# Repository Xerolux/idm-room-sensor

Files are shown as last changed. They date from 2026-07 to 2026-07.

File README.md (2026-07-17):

<div align="center">

# IDM Smart Climate Platform

**Open-source climate bridge, room sensing and condensation protection for IDM heat pumps**







</div>

> [!CAUTION]
> **Experimental developer edition. Not production-ready and not validated on a real IDM installation.**  
> Do not connect unverified hardware to a heat pump. Independent condensation protection remains mandatory for cooling tests.

<!-- SAFETY:NOT_PRODUCTION --><!-- SAFETY:WORK_IN_PROGRESS -->

## What this project contains

The platform combines three hardware approaches and a software-first GLT bridge:

| Component | Purpose | Status |
|---|---|---|
| ESP Room Sensor | Local SHT45 sensing, ESPHome, 0–10 V humidity and real KTY81-210 | Design prototype |
| Classic Sensor | Compact local sensor without Wi-Fi | Design prototype |
| Fake Sensor / Bridge | Receives HA/KNX/MQTT values and emulates the original IDM interface | Design prototype |
| Climate Engine | Selects the most critical room by dew-point margin | Functional HA example |
| `set_external_climate` | Native service present on `idm-heatpump-hass` main; stable-package fallback included here | Software tested, real device untested |
| Pipe Dew-Point Guard | Independent pipe-temperature/condensation safety concept | Documentation only |

## Confirmed original sensor information

The available LCN-FTW04 documentation identifies a combined room humidity/temperature sensor, a 0–10 V humidity output, KTY temperature element and 14–30 V DC supply. Only one room humidity sensor is intended for the Navigator; individual room temperatures may come from room units.

Current project terminal mapping must be verified against the exact IDM wiring diagram before connection:

| Function | Project signal |
|---|---|
| Supply | 14–30 V DC |
| Humidity | 0–10 V, working assumption 0–100 % RH |
| Temperature | KTY81-210 equivalent |
| Ground | Common reference |

## Preferred architecture

```text
KNX / ESPHome / Zigbee / MQTT room sensors
                    │
                    ▼
        Home Assistant Climate Engine
        - dew point per room
        - minimum dew-point margin
        - stale sensor detection
        - configurable fallback
                    │
          ┌─────────┴─────────┐
          ▼                   ▼
 GLT / Modbus registers   Analog fallback bridge
 1650…1663 temperature    0–10 V humidity
 1692 humidity            KTY emulation
          │                   │
          └─────────┬─────────┘
                    ▼
               IDM Navigator

Independent pipe dew-point switch / cooling inhibit
```

## Project checklist

### Documentation and repository
- [x] Professional README
- [x] GitHub Pages / Docsify structure
- [x] Wiki source pages
- [x] Issue and pull-request templates
- [x] Security, contributing and code-of-conduct files
- [x] Community test forms
- [x] Architecture and safety documentation

### Home Assistant and IDM integration
- [x] Multi-room climate-engine package selecting the highest dew point
- [x] Example automation for GLT register writes
- [x] Stale-input detection using Home Assistant `last_reported`
- [x] `set_external_climate` reference aligned with current upstream interfaces
- [x] Local service-contract and dew-point tests
- [x] Current register mapping reviewed against `idm-heatpump-api` main
- [ ] Release `set_external_climate` in a tagged `idm-heatpump-hass` version
- [ ] Real-device Modbus verification
- [ ] Confirm that the selected IDM configuration uses GLT values for cooling control

### ESPHome and firmware
- [x] ESPHome bridge configuration
- [x] Home Assistant-controlled temperature/humidity inputs
- [x] Stale-data timeout and conservative fallback concept
- [x] Dew-point calculation example
- [x] MCP4725 output component source
- [x] KTY lookup and calibration framework
- [x] Compile against the selected ESPHome release
- [x] Local authenticated web UI with confirmation-gated calibration/reset
- [x] Native ESP-IDF target with I/O, fail-safe runtime, NVS, API and OTA
- [ ] Hardware-in-the-loop test
- [ ] OTA recovery test

### Hardware
- [x] Block-level schematics and KiCad project structure
- [x] Board outlines and component placement concepts
- [x] Preliminary BOM and JLCPCB templates
- [x] Enclosure STL/OpenSCAD prototypes
- [ ] Replace every prototype symbol/footprint with verified manufacturer footprint
- [ ] Complete ERC/DRC with KiCad 9
- [ ] Review switch-mode power-supply layout against regulator datasheet
- [ ] Route and validate analog ground/current return paths
- [ ] Manufacture prototype
- [ ] Validate 0–10 V linearity and load drive
- [ ] Validate KTY emulation excitation voltage/current
- [ ] EMC, ESD, thermal and long-term tests

### Real installation
- [ ] Measure the original sensor at multiple humidity points
- [ ] Measure IDM KTY input using a resistance decade
- [ ] Confirm safe open-circuit and short-circuit behavior
- [ ] Heating-only observation
- [ ] Cooling test with independent dew-point switch
- [ ] Multi-week logging and fault injection

## Quick start for contributors

1. Read [Safety](pages/#/cooling-safety) and [Validation Plan](pages/#/validation).
2. Choose the next unblocked item from the [prioritized task list](TASKS.md).
3. Do not mark measurements as verified without raw data and test conditions.
4. Open an issue using the measurement or hardware-test template.

## Repository layout

```text
hardware/                 KiCad prototypes, BOM, CPL templates, enclosures
firmware/                 ESPHome and custom component sources
homeassistant/            Climate engine, automations and dashboard examples
idm-heatpump-hass/        Upstream service patch and tests
pages/                    GitHub Pages / Docsify site
wiki/                     GitHub Wiki source pages
docs/                     Technical documentation and validation plans
manufacturing/            Shared fabrication notes and release checklist
.github/                  Workflows, issue templates and contribution automation
```

ESPHome and native ESP-IDF builds use the pinned toolchains documented in
[firmware/BUILDING.md](firmware/BUILDING.md).

## Safety

This project is unaffiliated with IDM Energiesysteme. It is experimental open hardware. Incorrect humidity or temperature values can defeat condensation protection and cause water damage. Use an independent, hard-wired pipe dew-point switch during development and commissioning.

## Community Work Packages

- `work-packages/WP01-hardware`
- `work-packages/WP02-firmware`
- `work-packages/WP03-home-assistant`
- `work-packages/WP04-documentation`
- `work-packages/WP05-validation`

See the [prioritized task list](TASKS.md) and the compact
[project-status summary](PROJECT_STATUS.md).

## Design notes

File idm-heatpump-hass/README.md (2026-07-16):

# Proposed upstream changes

The current `idm-heatpump-hass` main branch contains
`idm_heatpump.set_external_climate` (commit `bd41999`, 2026-07-16). This
directory now preserves a dependency-light contract reference and standalone
tests for review from the climate-platform side.

The service has not yet shipped in a tagged release and has not been validated
against a real heat pump. The Home Assistant package therefore uses
`write_register` for v0.8.2 compatibility.

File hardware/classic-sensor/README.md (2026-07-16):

# IDM-RoomSensor-Classic Rev. A

Enthalten: KiCad-Schaltplan, PCB-Layout/Platzierung, BOM, Firmware-Grundlage und Gehäuse als STL/OpenSCAD.

**Versorgung:** Die Classic-Platine wird aus den 24 V der IDM versorgt und besitzt kein WLAN/ESP.

IDM-Klemmen: 43=KTY-Temperatursignal, 42=+14–32 V DC, 41=gemeinsamer GND/KTY-Rückleiter, 40=Feuchte 0–10 V.

Annahme: 0 V = 0 % rF, 10 V = 100 % rF.

## Status
Rev.-A-Entwicklungsgrundlage, **nicht produktionsfreigegeben**. Vor Bestellung und Anschluss: Footprints, ERC/DRC, Analogskalierung, Schutzbeschaltung, EMV und reale IDM-Kennlinie prüfen und kalibrieren.

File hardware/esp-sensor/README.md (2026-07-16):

# IDM-RoomSensor-ESP Rev. A

Enthalten: KiCad-Schaltplan, PCB-Layout/Platzierung, BOM, Firmware-Grundlage und Gehäuse als STL/OpenSCAD.

**Versorgung:** Der ESP wird über die 24 V der IDM versorgt; 24 V werden auf 5 V und 3,3 V gewandelt.

IDM-Klemmen: 43=KTY-Temperatursignal, 42=+14–32 V DC, 41=gemeinsamer GND/KTY-Rückleiter, 40=Feuchte 0–10 V.

Annahme: 0 V = 0 % rF, 10 V = 100 % rF.

## Status
Rev.-A-Entwicklungsgrundlage, **nicht produktionsfreigegeben**. Vor Bestellung und Anschluss: Footprints, ERC/DRC, Analogskalierung, Schutzbeschaltung, EMV und reale IDM-Kennlinie prüfen und kalibrieren.

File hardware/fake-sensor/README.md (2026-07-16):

# IDM Fake Sensor ESP – Revision A

Diese Platine empfängt Temperatur- und Feuchtewerte aus Home Assistant und simuliert gegenüber der IDM AERO ALM den originalen Temperatur-/Feuchtesensor.

## Ausgänge

| IDM-Klemme | Signal |
|---|---|
| 43 | emuliertes KTY-Temperatursignal |
| 42 | +14–32 V DC Versorgung |
| 41 | gemeinsamer GND/KTY-Rückleiter |
| 40 | simulierte Feuchte 0–10 V |

Der ESP32 wird vollständig aus den 24 V der IDM versorgt.

## Home Assistant

Home Assistant setzt zwei ESPHome-Number-Entitäten:

- simulierte relative Feuchte
- simulierte Raumtemperatur

Damit können Mittelwerte, Maximalwerte oder der ungünstigste Raum an die Wärmepumpe weitergegeben werden. Für die Kühlung sollte eher der **kritischste Raum** verwendet werden als ein Durchschnitt.

## Fail-safe

Bei fehlenden Aktualisierungen werden standardmäßig ausgegeben:

- 80 % rF
- 28 °C

Die Werte sind absichtlich konservativ. Zusätzlich sollte die vorhandene Taupunktüberwachung der Anlage aktiv bleiben.

## Wichtige technische Einschränkung

Die Feuchtesimulation ist klar: DAC plus Operationsverstärker erzeugen 0–10 V.

Die Temperatursimulation muss noch elektrisch validiert werden. Der Entwurf verwendet einen Digitalpotentiometer plus Festwiderstandsnetzwerk zur Nachbildung eines KTY81-210. Vor Anschluss müssen an der IDM gemessen werden:

1. Leerlaufspannung an 43 gegen 41,
2. Messstrom durch einen echten KTY81-210,
3. zulässige Spannung an den Anschlüssen des Digitalpotentiometers,
4. tatsächliche Widerstandskennlinie, die die IDM erwartet.

Falls Spannung oder Strom für einen Digitalpotentiometer ungeeignet sind, muss die Temperaturstufe durch eine galvanisch isolierte Widerstandsmatrix oder PhotoMOS-Lösung ersetzt werden.

## Status des Layouts

Das KiCad-PCB enthält Boardkontur und Bauteilplatzierung. Es ist eine Rev.-A-Entwicklungsgrundlage und **nicht produktionsfreigegeben**. Vor Bestellung:

- Footprints kontrollieren,
- Schaltplan in modernes KiCad-Format übernehmen,
- vollständig routen,
- ERC/DRC ausführen,
- 0–10-V-Verstärkung dimensionieren,
- Temperaturstufe vermessen und kalibrieren,
- EMV- und Schutzbeschaltung prüfen.

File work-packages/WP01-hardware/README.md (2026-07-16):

# Hardware engineering

- [ ] Power and protection review
- [ ] 0–10 V stage
- [ ] KTY emulation
- [ ] PCB routing
- [ ] Fabrication outputs
- [ ] Enclosures
- [ ] Test points

Results must include conditions, equipment and raw data.

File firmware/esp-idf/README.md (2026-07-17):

# Native ESP-IDF firmware

This target implements the fake-sensor bridge directly on ESP-IDF. It shares
the host-tested dew-point, quality, bridge-state, calibration and analog-output
cores with the ESPHome variant.

> [!CAUTION]
> This remains experimental firmware for unverified prototype hardware. It
> does not replace an independent, hard-wired condensation guard.

## Implemented behavior

- boots into configured fail-safe humidity and temperature values before
  networking starts;
- drives an MCP4725 humidity DAC and AD5242 temperature digipot over I2C;
- validates humidity, temperature, source length and command quality;
- returns to fail-safe output after the command stale timeout;
- latches output failures, retries the I2C path and reports recovery;
- stores CRC-protected calibration V2 records in NVS, verifies writes and
  migrates valid V1 records;
- connects as a Wi-Fi station when an SSID is configured and otherwise remains
  local-only;
- exposes versioned diagnostics and authenticated mutation endpoints;
- uses the ESP task watchdog, brownout detection and OTA rollback support;
- accepts only HTTPS OTA URLs using the ESP certificate bundle;
- confirms a new OTA image only after a health window, never blindly at boot;
- redacts sensor data on the diagnostics endpoint when no API token is set.

## Build

PlatformIO 6.1.19 and the pinned pioarduino ESP32 platform are used for the
reproducible build:

```bash
python3 -m pip install platformio==6.1.19
make build-esp-idf
```

The equivalent direct command is:

```bash
platformio run --project-dir firmware/esp-idf
```

The generated `sdkconfig.idm-native` and `.pio/` directory are local build
artifacts and are ignored.

## Configuration

Run PlatformIO's ESP-IDF menu configuration and open **IDM native firmware**:

```bash
platformio run --project-dir firmware/esp-idf --target menuconfig
```

At minimum, review:

- Wi-Fi SSID/password and hostname;
- a random HTTP bearer token of at least 16 characters;
- I2C pins and device addresses;
- fail-safe values, stale timeout and minimum command quality;
- factory analog calibration.

An empty Wi-Fi SSID keeps the target local-only. An empty API token disables
every mutating endpoint. The diagnostic endpoint remains readable without a
token, but when no token is configured it **redacts** sensor values
(effective humidity/temperature, dew point, command source, output codes) and
publishes only operational fields (bridge state, safe/stale/fault flags,
uptime, heap). Configure `IDM_API_TOKEN` to receive full diagnostics behind
the same bearer gate as the mutating endpoints.

The HTTP API itself is not TLS-protected. Operate it only on a trusted,
isolated commissioning network; the bearer token must not be exposed across
an untrusted network.

## HTTP API

Replace `DEVICE`, `TOKEN` and values below as appropriate.

Read the payload defined by
[`diagnostics.schema.json`](diagnostics.schema.json):

```bash
curl http://DEVICE/api/v1/diagnostics
```

Submit an atomic climate command:

```bash
curl -X POST http://DEVICE/api/v1/climate \
  -H "Authorization: Bearer TOKEN" \
  -H "Content-Type: application/json" \
  -d '{"humidity":58.0,"temperature":23.5,"quality":100,"source":"commissioning"}'
```

Immediately request the configured safe fallback:

```bash
curl -X POST http://DEVICE/api/v1/fallback \
  -H "Authorization: Bearer TOKEN"
```

Calibration writes are bounded by the same core validation as the ESPHome
target and require an explicit confirmation header:

```bash
curl -X POST http://DEVICE/api/v1/calibration \
  -H "Authorization: Bearer TOKEN" \
  -H "X-IDM-Confirm: apply-calibration" \
  -H "Content-Type: application/json" \
  -d '{"humidity_code_min":0,"humidity_code_max":4095,"temperature_resistance_min":650.0,"temperature_resistance_max":3000.0,"temperature_code_inverted":false}'
```

Reset calibration to configured factory values:

```bash
curl -X POST http://DEVICE/api/v1/calibration/reset \
  -H "Authorization: Bearer TOKEN" \
  -H "X-IDM-Confirm: reset-calibration"
```

Queue a firmware image from a trusted HTTPS host:

```bash
curl -X POST http://DEVICE/api/v1/ota \
  -H "Authorization: Bearer TOKEN" \
  -H "X-IDM-Confirm: firmware-update" \
  -H "Content-Type: application/json" \
  -d '{"url":"https://example.invalid/idm-native.bin"}'
```

By default any HTTPS host is accepted (relying on the ESP certificate bundle).
For field deployments, set `IDM_OTA_ALLOWED_HOST` to the exact download
hostname so a compromised token cannot redirect the device at an arbitrary
host. A pending image is only marked valid after `IDM_OTA_HEALTH_SECONDS`
(default 30 s) of healthy main-loop operation; a crash-looping image rolls
back to the previous slot automatically. Interrupted or unbootable OTA images
are otherwise handled by the configured dual-OTA partition table and
bootloader rollback support. Recovery behavior still requires a physical
fault-injection test before real installation.

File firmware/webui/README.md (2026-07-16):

# Local web UI

The fake-sensor firmware exposes ESPHome web-server version 3 on port 80.
The page assets are embedded in the firmware, browser OTA is disabled for this
web server, and HTTP basic authentication is required.

Before flashing, override the deliberately conspicuous example password
`CHANGE-ME-BEFORE-INSTALLATION` in the device substitutions. The web UI must
only be reachable from a trusted commissioning network; HTTP basic
authentication does not provide transport encryption.

## Sections

- **Status:** effective humidity and temperature, bridge state, fallback,
  staleness, output readiness, faults, RSSI and uptime.
- **Commands:** the current humidity and temperature command plus source and
  quality.
- **Calibration:** editable DAC endpoints, KTY resistance endpoints,
  inversion, stored calibration state and a reload action.
- **Safety:** explicit confirmation plus apply and factory-reset actions.
- **Diagnostics:** raw output values and a versioned JSON export.

The machine-readable UI contract is
[`manifest.json`](manifest.json), validated by [`schema.json`](schema.json).
The implementation is
[`../esphome/packages/fake-sensor-webui.yaml`](../esphome/packages/fake-sensor-webui.yaml).

## Confirmation flow

Calibration changes are only editor values until **IDM Web Apply Calibration**
is pressed. Applying calibration and resetting to factory calibration both
require **IDM Web Confirm Dangerous Action** to be enabled first. Confirmation
expires after 60 seconds and is consumed by the next apply or reset attempt.
Invalid endpoint ordering is rejected by the firmware and the editor is
reloaded from the active calibration.

## Diagnostic export

The text-sensor endpoint is:

`/text_sensor/idm_webui_diagnostic_export`

It returns the standard ESPHome entity response whose `value` contains a JSON
document. That nested document follows
[`diagnostic-export.schema.json`](diagnostic-export.schema.json). The export
updates every 30 seconds and can also be refreshed from the web UI.

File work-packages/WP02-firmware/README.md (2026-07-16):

# Embedded firmware

- [x] ESPHome bridge
- [x] Native ESP-IDF
- [x] MQTT discovery
- [x] Fail-safe state machine
- [x] Calibration storage
- [x] Web UI
- [x] OTA implementation and rollback configuration
- [ ] OTA interruption/recovery bench test

Results must include conditions, equipment and raw data.

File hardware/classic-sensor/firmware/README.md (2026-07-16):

# Firmware-Grundlage
ATtiny1616 liest SHT45, begrenzt 0–100 % rF und schreibt MCP4725:
DAC = rF / 100 × 4095. Watchdog aktivieren; bei Sensorfehler sicheren hohen Feuchtewert ausgeben.

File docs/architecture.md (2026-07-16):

# IDM Smart Climate Platform

## Ziel

Temperatur- und Feuchtewerte können aus KNX, ESPHome, Zigbee, MQTT, Home Assistant oder lokalen Sensoren stammen. Die Plattform berechnet je Raum Taupunkt und Taupunktabstand und übergibt den kritischsten gültigen Wert an die IDM.

## Übertragungswege

1. **GLT/Modbus über `idm-heatpump-hass`** – bevorzugter Weg.
2. **Fake-Sensor-Platine** – 0–10 V Feuchte und KTY-Nachbildung.
3. **Lokaler Sensor** – autonomer Fallback bei Netzwerk- oder HA-Ausfall.

## Relevante Register

| Funktion | Register | Typ |
|---|---:|---|
| Externe Raumtemperatur HK A | 1650–1651 | FLOAT |
| HK B | 1652–1653 | FLOAT |
| HK C | 1654–1655 | FLOAT |
| HK D | 1656–1657 | FLOAT |
| HK E | 1658–1659 | FLOAT |
| HK F | 1660–1661 | FLOAT |
| HK G | 1662–1663 | FLOAT |
| Externe Feuchte GLT | 1692–1693 | FLOAT |

## Auswahlstrategie

Für die Kühlung sollte nicht pauschal ein Mittelwert verwendet werden. Bevorzugt wird der Raum mit dem kleinsten Abstand zwischen Raumtemperatur und Taupunkt. Optional können Maximalfeuchte, fester Referenzraum oder ein eigenes Template verwendet werden.

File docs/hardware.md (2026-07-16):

# Hardwareübersicht

## ESP Sensor

- ESP32-C3-MINI-1
- SHT45
- 24-V-Eingang mit Schutzbeschaltung
- 24 V → 5 V → 3,3 V
- MCP4725-DAC
- OPA197-Verstärker für 0–10 V
- echter KTY81-210
- ESPHome, WLAN und OTA

## Classic Sensor

- ATtiny1616
- SHT45
- MCP4725-DAC
- OPA197-Verstärker
- echter KTY81-210
- keine Netzwerkabhängigkeit
- kleineres Gehäuse

## Fake Sensor

- ESP32-C3-MINI-1
- MCP4725 und OPA197 für 0–10 V
- programmierbares Widerstandsnetzwerk für die Temperatur
- Home-Assistant-Werte als Quelle
- konfigurierbare Fallback-Werte
- Watchdog und Kommunikations-Timeout

> Die KTY-Emulation des Fake Sensors ist noch nicht elektrisch validiert.

## Bestätigte Originalbelegung

| IDM | Sensor | Funktion |
|---:|---:|---|
| 43 | 2 | KTY-Temperatursignal |
| 42 | 7 | +14–32 V DC |
| 41 | 3 und 6 | KTY-Rückleiter und GND |
| 40 | 5 | Feuchte 0–10 V |

Der Anschluss benötigt vier Adern; die beiden Rückleiter werden am Sensor bzw. auf der Platine gemeinsam auf Klemme 41 geführt.

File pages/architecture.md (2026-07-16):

# Architecture

The preferred path is software-first via writable GLT registers, with the analog bridge retained as a compatibility and fallback option. Sensor fusion must select the smallest dew-point margin, not merely the largest humidity.

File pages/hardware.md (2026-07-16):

# Hardware

Three prototype boards are included. Their files are design inputs, not fabrication releases. See the validation gates before ordering.

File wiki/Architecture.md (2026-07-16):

# Architecture

Software-first GLT path, analog fallback and independent safety chain.

> Status: Work in progress. Contributions and measurements are welcome.

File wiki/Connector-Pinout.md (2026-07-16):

# Connector Pinout

See `docs/hardware/connector-pinout.md`.

- [ ] Community reviewed
- [ ] Validated

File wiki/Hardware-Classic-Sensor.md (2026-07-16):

# Hardware Classic Sensor

Compact non-networked sensor.

> Status: Work in progress. Contributions and measurements are welcome.

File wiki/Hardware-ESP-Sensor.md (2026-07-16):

# Hardware ESP Sensor

Local sensing board with ESPHome.

> Status: Work in progress. Contributions and measurements are welcome.

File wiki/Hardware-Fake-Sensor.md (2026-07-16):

# Hardware Fake Sensor

HA/KNX/MQTT-to-IDM analog bridge.

> Status: Work in progress. Contributions and measurements are welcome.

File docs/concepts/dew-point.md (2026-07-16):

# Dew Point

The dew point is the temperature at which water vapour condenses. Radiant cooling surfaces must stay above it with a safety margin.

The firmware and validation tool use the Magnus approximation. Non-finite
inputs, humidity at or below 0 %, humidity above 100 %, and temperatures
outside the formula domain are rejected instead of being silently clamped.
Callers must select their conservative fallback path for such values.

## Status

- [x] Formula and invalid-input unit tests
- [ ] Bench tested
- [ ] Real-device tested

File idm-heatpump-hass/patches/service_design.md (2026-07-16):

# Service design

Resolve existing register definitions, validate writability, finiteness and
metadata ranges, then perform the requested writes. Register resolution for
temperature and humidity must finish before the first write to prevent a
missing optional humidity register from causing a partial update.

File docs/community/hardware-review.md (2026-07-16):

# Hardware Review

Review ratings, stability, protection, pinout, testability and failure modes.

## Status

- [ ] Reviewed
- [ ] Bench tested
- [ ] Real-device tested

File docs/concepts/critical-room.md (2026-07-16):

# Critical Room

The critical room has the smallest dew-point margin, not necessarily the highest humidity.

## Status

- [ ] Reviewed
- [ ] Bench tested
- [ ] Real-device tested

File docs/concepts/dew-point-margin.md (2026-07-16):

# Dew Point Margin

Use surface temperature minus dew point. Software must not be the only condensation protection.

## Status

- [ ] Reviewed
- [ ] Bench tested
- [ ] Real-device tested

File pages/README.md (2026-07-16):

# IDM Smart Climate Platform

🚧 **Work in progress / experimental developer edition**

This site documents the room-sensor, GLT bridge and independent
condensation-protection concepts. The ESPHome and native ESP-IDF firmware
targets are source-, contract- and compile-tested; physical analog, watchdog
and OTA recovery tests remain open. Start with
[Architecture](architecture.md) and [Safety](cooling-safety.md).

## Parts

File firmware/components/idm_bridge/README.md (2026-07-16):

# IDM bridge component

`idm_bridge` owns the command lifecycle between Home Assistant/ESPHome and the
analog sensor-emulation outputs.

## Safety behaviour

- Startup immediately selects the configured fallback values.
- Temperature and humidity are accepted atomically.
- Non-finite or out-of-range values are rejected and replace both outputs with
  the fallback pair.
- The last valid command expires after `stale_timeout`.
- A reported hardware-output fault is latched and selects the fallback pair.
- Clearing an output fault does not restore an old command. A new valid command
  is required.
- The timeout calculation is safe across the 32-bit `millis()` wraparound.
- Stored calibration is accepted only after version, CRC and range checks.

The component exposes normalized `FloatOutput` ports:

- humidity: `0.0` for 0 % and `1.0` for 100 %
- temperature: `0.0` for -20 °C and `1.0` for 60 °C

The concrete DAC and KTY-emulation drivers and their calibrated transfer
functions are implemented by the optional atomic `analog_output` driver. It
writes the MCP4725 DAC register and AD5242 RDAC1 in one bridge update. If either
I²C transaction fails, the bridge latches an output fault and retries the safe
fallback pair.

The committed KTY table and resistance-to-code limits are prototype values, not
validated installation calibration. Enabling the driver therefore requires the
explicit `accept_unverified_kty_calibration: true` acknowledgement and remains
limited to isolated bench testing until SAFE-02 and SAFE-03 are complete.

## Actions

```yaml
- idm_bridge.set_values:
    id: climate_bridge
    humidity: 60
    temperature: 23

- idm_bridge.apply_fallback: climate_bridge

- idm_bridge.set_output_fault:
    id: climate_bridge
    active: true

- idm_bridge.set_calibration:
    id: idm_analog_outputs
    humidity_dac_min_code: 100
    humidity_dac_max_code: 3900
    temperature_resistance_min: 700
    temperature_resistance_max: 3200
    temperature_code_inverted: false

- idm_bridge.reset_calibration: idm_analog_outputs
```

`set_output_fault` is intended for an output driver that detects an I/O or
calibration failure.

## Analog protocol

- MCP4725: DAC-register write command `0x40` followed by the 12-bit code.
- AD5242: instruction byte `0x00` selects RDAC1 without reset or shutdown,
  followed by the 8-bit wiper code.

The humidity code range and temperature resistance endpoints are configurable
so measured calibration can replace the prototype defaults without changing
driver code.

## Calibration persistence

The YAML values are immutable factory defaults. Runtime updates are stored as a
version-2 ESPHome preference record with magic, size, flags and CRC-32. The
component reads the record back before activating it. Invalid data selects the
factory values and publishes `invalid_using_factory`; it never restores a
legacy record when a current record is present but corrupt.

Version-1 gain/offset records are migrated once and rewritten as version 2.
`calibration_preference_id` must remain stable across YAML ID renames. See
[`docs/firmware/calibration-storage.md`](../../../docs/firmware/calibration-storage.md)
for the exact format, ranges and status values.

Protocol implementation references:

- [Microchip MCP4725 data sheet](https://ww1.microchip.com/downloads/en/DeviceDoc/MCP4725-Data-Sheet-20002039E.pdf)
- [Analog Devices AD5241/AD5242 data sheet](https://www.analog.com/media/en/technical-documentation/data-sheets/ad5241_ad5242.pdf)

## States

| State | Meaning |
|---|---|
| `startup_safe` | Booted with fallback values; no valid command received |
| `active` | A valid, non-expired command is active |
| `manual_safe` | Fallback was explicitly requested |
| `stale_safe` | The command timed out |
| `invalid_safe` | An invalid command was rejected |
| `output_fault_safe` | The output driver reported a fault |

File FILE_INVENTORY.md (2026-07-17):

# File inventory

Auto-generated by `tools/generate_file_inventory.py` from `git ls-files`. Do not edit by hand; run the generator instead.

- `.github/ISSUE_TEMPLATE/bug_report.yml`
- `.github/ISSUE_TEMPLATE/config.yml`
- `.github/ISSUE_TEMPLATE/feature_request.yml`
- `.github/ISSUE_TEMPLATE/hardware_test.yml`
- `.github/ISSUE_TEMPLATE/measurement_report.yml`
- `.github/dependabot.yml`
- `.github/pull_request_template.md`
- `.github/requirements-ci.txt`
- `.github/workflows/docs.yml`
- `.github/workflows/esphome.yml`
- `.github/workflows/kicad-check.yml`
- `.github/workflows/pages.yml`
- `.github/workflows/yaml-check.yml`
- `.gitignore`
- `CHANGELOG.md`
- `CODE_OF_CONDUCT.md`
- `CONTRIBUTING.md`
- `FILE_INVENTORY.md`
- `LICENSE`
- `Makefile`
- `PROJECT_STATUS.md`
- `README.md`
- `ROADMAP.md`
- `SECURITY.md`
- `TASKS.md`
- `docs/adr/ADR-001-mcu.md`
- `docs/adr/ADR-002-humidity-sensor.md`
- `docs/adr/ADR-003-dac.md`
- `docs/adr/ADR-004-opamp.md`
- `docs/adr/ADR-005-power.md`
- `docs/adr/ADR-006-temp-emulation.md`
- `docs/adr/ADR-007-pipe-sensor.md`
- `docs/architecture.md`
- `docs/community/hardware-review.md`
- `docs/community/tester-guide.md`
- `docs/concepts/critical-room.md`
- `docs/concepts/dew-point-margin.md`
- `docs/concepts/dew-point.md`
- `docs/concepts/fail-safe.md`
- `docs/concepts/sensor-fusion.md`
- `docs/cooling-safety.md`
- `docs/firmware/calibration-storage.md`
- `docs/firmware/source-quality.md`
- `docs/firmware/state-machine.md`
- `docs/firmware/watchdog.md`
- `docs/hardware.md`
- `docs/hardware/connector-pinout.md`
- `docs/hardware/humidity-output.md`
- `docs/hardware/kty-emulation.md`
- `docs/hardware/pipe-sensor.md`
- `docs/hardware/power-input.md`
- `docs/hardware/test-points.md`
- `docs/help-wanted.md`
- `docs/home-assistant/helpers.md`
- `docs/home-assistant/stale-data.md`
- `docs/home-assistant/strategy-critical-margin.md`
- `docs/home-assistant/strategy-max-humidity.md`
- `docs/home-assistant/strategy-weighted.md`
- `docs/images/classic-sensor-pcb.svg`
- `docs/images/esp-sensor-pcb.svg`
- `docs/images/fake-sensor-pcb.svg`
- `docs/installation.md`
- `docs/modbus-glt.md`
- `docs/ordering/alternatives.md`
- `docs/ordering/prototype-order.md`
- `docs/original-sensor.md`
- `docs/protocols/analog-interface.md`
- `docs/protocols/esphome.md`
- `docs/protocols/knx.md`
- `docs/protocols/modbus-tcp.md`
- `docs/protocols/mqtt.md`
- `docs/repository-settings.md`
- `docs/safety.md`
- `docs/superpowers/specs/2026-07-17-hardening-and-cleanup-design.md`
- `docs/validation.md`
- `docs/validation/fail-safe-test.md`
- `docs/validation/idm-input-test.md`
- `docs/validation/measurement-template.md`
- `docs/validation/original-sensor-test.md`
- `docs/validation/thermal-test.md`
- `firmware/.gitignore`
- `firmware/BUILDING.md`
- `firmware/LICENSE`
- `firmware/common/dew_point.h`
- `firmware/common/kty_table.csv`
- `firmware/common/value_quality.h`
- `firmware/components/idm_bridge/README.md`
- `firmware/components/idm_bridge/__init__.py`
- `firmware/components/idm_bridge/idm_analog_output.cpp`
- `firmware/components/idm_bridge/idm_analog_output.h`
- `firmware/components/idm_bridge/idm_analog_output_core.h`
- `firmware/components/idm_bridge/idm_bridge.cpp`
- `firmware/components/idm_bridge/idm_bridge.h`
- `firmware/components/idm_bridge/idm_bridge_core.h`
- `firmware/components/idm_bridge/idm_calibration_storage_core.h`
- `firmware/esp-idf/CMakeLists.txt`
- `firmware/esp-idf/README.md`
- `firmware/esp-idf/diagnostics.schema.json`
- `firmware/esp-idf/main/CMakeLists.txt`
- `firmware/esp-idf/main/Kconfig.projbuild`
- `firmware/esp-idf/main/main.cpp`
- `firmware/esp-idf/main/native_runtime.h`
- `firmware/esp-idf/partitions.csv`
- `firmware/esp-idf/platformio.ini`
- `firmware/esp-idf/sdkconfig.defaults`
- `firmware/esp-sensor-esphome.yaml`
- `firmware/esphome/package-test.yaml`
- `firmware/esphome/packages/base.yaml`
- `firmware/esphome/packages/diagnostics.yaml`
- `firmware/esphome/packages/fake-sensor-mqtt.yaml`
- `firmware/esphome/packages/fake-sensor-webui.yaml`
- `firmware/esphome/packages/fallback.yaml`
- `firmware/esphome/packages/local-sht45.yaml`
- `firmware/esphome/packages/mqtt.yaml`
- `firmware/esphome/packages/pipe-sensor.yaml`
- `firmware/esphome/packages/room-sensor-mqtt.yaml`
- `firmware/fake-sensor-bridge.yaml`
- `firmware/fake-sensor-esphome.yaml`
- `firmware/mqtt/bridge-diagnostics.schema.json`
- `firmware/mqtt/climate-command.schema.json`
- `firmware/mqtt/room-diagnostics.schema.json`
- `firmware/mqtt/topics.md`
- `firmware/requirements.txt`
- `firmware/webui/README.md`
- `firmware/webui/diagnostic-export.schema.json`
- `firmware/webui/manifest.json`
- `firmware/webui/schema.json`
- `hardware/classic-sensor/BOM.csv`
- `hardware/classic-sensor/IDM-RoomSensor-Classic.kicad_pcb`
- `hardware/classic-sensor/IDM-RoomSensor-Classic.pro`
- `hardware/classic-sensor/IDM-RoomSensor-Classic.sch`
- `hardware/classic-sensor/README.md`
- `hardware/classic-sensor/enclosure/PRINTING.md`
- `hardware/classic-sensor/enclosure/idm-roomsensor-classic.scad`
- `hardware/classic-sensor/enclosure/idm-roomsensor-classic_base.stl`
- `hardware/classic-sensor/enclosure/idm-roomsensor-classic_lid.stl`
- `hardware/classic-sensor/firmware/README.md`
- `hardware/classic-sensor/manufacturing/GERBER_STATUS.txt`
- `hardware/classic-sensor/manufacturing/JLCPCB_BOM.csv`
- `hardware/classic-sensor/manufacturing/JLCPCB_CPL.csv`
- `hardware/classic-sensor/manufacturing/README.md`
- `hardware/esp-sensor/BOM.csv`
- `hardware/esp-sensor/IDM-RoomSensor-ESP.kicad_pcb`
- `hardware/esp-sensor/IDM-RoomSensor-ESP.pro`
- `hardware/esp-sensor/IDM-RoomSensor-ESP.sch`
- `hardware/esp-sensor/README.md`
- `hardware/esp-sensor/enclosure/PRINTING.md`
- `hardware/esp-sensor/enclosure/idm-roomsensor-esp.scad`
- `hardware/esp-sensor/enclosure/idm-roomsensor-esp_base.stl`
- `hardware/esp-sensor/enclosure/idm-roomsensor-esp_lid.stl`
- `hardware/esp-sensor/firmware/esphome.yaml`
- `hardware/esp-sensor/manufacturing/GERBER_STATUS.txt`
- `hardware/esp-sensor/manufacturing/JLCPCB_BOM.csv`
- `hardware/esp-sensor/manufacturing/JLCPCB_CPL.csv`
- `hardware/esp-sensor/manufacturing/README.md`
- `hardware/fake-sensor/BOM.csv`
- `hardware/fake-sensor/CALIBRATION.md`
- `hardware/fake-sensor/DESIGN_STATUS.md`
- `hardware/fake-sensor/IDM-FakeSensor-ESP.kicad_pcb`
- `hardware/fake-sensor/IDM-FakeSensor-ESP.pro`
- `hardware/fake-sensor/IDM-FakeSensor-ESP.sch`
- `hardware/fake-sensor/README.md`
- `hardware/fake-sensor/TEST_PLAN.md`
- `hardware/fake-sensor/enclosure/PRINTING.md`
- `hardware/fake-sensor/enclosure/idm_fake_sensor.scad`
- `hardware/fake-sensor/enclosure/idm_fake_sensor_base.stl`
- `hardware/fake-sensor/enclosure/idm_fake_sensor_lid.stl`
- `hardware/fake-sensor/fabrication/BOM-template.csv`
- `hardware/fake-sensor/fabrication/CPL-template.csv`
- `hardware/fake-sensor/fabrication/README.md`
- `hardware/fake-sensor/firmware/esphome.yaml`
- `hardware/fake-sensor/home_assistant/automation_example.yaml`
- `hardware/fake-sensor/manufacturing/GERBER_STATUS.txt`
- `hardware/fake-sensor/manufacturing/JLCPCB_BOM.csv`
- `hardware/fake-sensor/manufacturing/JLCPCB_CPL.csv`
- `hardware/fake-sensor/manufacturing/README.md`
- `hardware/gateway/DESIGN_STATUS.md`
- `hardware/gateway/TEST_PLAN.md`
- `hardware/gateway/fabrication/BOM-template.csv`
- `hardware/gateway/fabrication/CPL-template.csv`
- `hardware/gateway/fabrication/README.md`
- `hardware/pipe-safety/DESIGN_STATUS.md`
- `hardware/pipe-safety/TEST_PLAN.md`
- `hardware/pipe-safety/fabrication/BOM-template.csv`
- `hardware/pipe-safety/fabrication/CPL-template.csv`
- `hardware/pipe-safety/fabrication/README.md`
- `hardware/room-sensor-classic/DESIGN_STATUS.md`
- `hardware/room-sensor-classic/TEST_PLAN.md`
- `hardware/room-sensor-classic/fabrication/BOM-template.csv`
- `hardware/room-sensor-classic/fabrication/CPL-template.csv`
- `hardware/room-sensor-classic/fabrication/README.md`
- `hardware/room-sensor-esp/DESIGN_STATUS.md`
- `hardware/room-sensor-esp/TEST_PLAN.md`
- `hardware/room-sensor-esp/fabrication/BOM-template.csv`
- `hardware/room-sensor-esp/fabrication/CPL-template.csv`
- `hardware/room-sensor-esp/fabrication/README.md`
- `homeassistant/blueprints/automation/cooling_inhibit.yaml`
- `homeassistant/blueprints/automation/critical_room.yaml`
- `homeassistant/blueprints/automation/stale_guard.yaml`
- `homeassistant/climate-engine-package.yaml`
- `homeassistant/dashboard-example.yaml`
- `homeassistant/examples/rooms/room_01.yaml`
- `homeassistant/examples/rooms/room_02.yaml`
- `homeassistant/examples/rooms/room_03.yaml`
- `homeassistant/examples/rooms/room_04.yaml`
- `homeassistant/examples/rooms/room_05.yaml`
- `homeassistant/examples/rooms/room_06.yaml`
- `homeassistant/examples/rooms/room_07.yaml`
- `homeassistant/examples/rooms/room_08.yaml`
- `homeassistant/examples/rooms/room_09.yaml`
- `homeassistant/examples/rooms/room_10.yaml`
- `homeassistant/examples/rooms/room_11.yaml`
- `homeassistant/examples/rooms/room_12.yaml`
- `homeassistant/examples/rooms/room_13.yaml`
- `homeassistant/examples/rooms/room_14.yaml`
- `homeassistant/examples/rooms/room_15.yaml`
- `homeassistant/examples/rooms/room_16.yaml`
- `homeassistant/examples/rooms/room_17.yaml`
- `homeassistant/examples/rooms/room_18.yaml`
- `homeassistant/examples/rooms/room_19.yaml`
- `homeassistant/examples/rooms/room_20.yaml`
- `homeassistant/fake-sensor-automation.yaml`
- `idm-heatpump-hass/IMPLEMENTATION.md`
- `idm-heatpump-hass/README.md`
- `idm-heatpump-hass/patches/service_design.md`
- `idm-heatpump-hass/patches/set_external_climate_services.yaml`
- `idm-heatpump-hass/patches/test_matrix.md`
- `idm-heatpump-hass/services.yaml.patch`
- `idm-heatpump-hass/services_implementation.py`
- `idm-heatpump-hass/test_services_external_climate.py`
- `manufacturing/release-checklist.md`
- `pages/README.md`
- `pages/_navbar.md`
- `pages/_sidebar.md`
- `pages/architecture.md`
- `pages/cooling-safety.md`
- `pages/esphome.md`
- `pages/faq.md`
- `pages/hardware.md`
- `pages/help-wanted.md`
- `pages/home-assistant.md`
- `pages/index.html`
- `pages/native-esp-idf.md`
- `pages/troubleshooting.md`
- `pages/validation.md`
- `tests/cpp/firmware_common_test.cpp`
- `tests/cpp/idm_analog_output_core_test.cpp`
- `tests/cpp/idm_bridge_core_test.cpp`
- `tests/cpp/idm_calibration_storage_core_test.cpp`
- `tests/cpp/idm_native_runtime_test.cpp`
- `tests/test_climate_template.py`
- `tests/test_dew_point.py`
- `tests/test_esp_idf_native.py`
- `tests/test_firmware_common.py`
- `tests/test_homeassistant_blueprints.py`
- `tests/test_idm_analog_output_core.py`
- `tests/test_idm_bridge_core.py`
- `tests/test_idm_calibration_storage_core.py`
- `tests/test_idm_native_runtime.py`
- `tests/test_mqtt_contract.py`
- `tests/test_webui_contract.py`
- `tools/check_esphome.py`
- `tools/check_repo.py`
- `tools/dew_point.py`
- `tools/generate_file_inventory.py`
- `tools/generate_room_examples.py`
- `validation/protocols/ha-loss.md`
- `validation/protocols/humidity-output.md`
- `validation/protocols/kty-input.md`
- `validation/protocols/long-term.md`
- `validation/protocols/mqtt-loss.md`
- `validation/protocols/power-input.md`
- `validation/protocols/real-idm.md`
- `validation/protocols/sensor-loss.md`
- `validation/protocols/thermal.md`
- `validation/protocols/wifi-loss.md`
- `validation/raw-data/ha-loss.csv`
- `validation/raw-data/humidity-output.csv`
- `validation/raw-data/kty-input.csv`
- `validation/raw-data/long-term.csv`
- `validation/raw-data/mqtt-loss.csv`
- `validation/raw-data/power-input.csv`
- `validation/raw-data/real-idm.csv`
- `validation/raw-data/sensor-loss.csv`
- `validation/raw-data/thermal.csv`
- `validation/raw-data/wifi-loss.csv`
- `wiki/Analog-Interface.md`
- `wiki/Architecture.md`
- `wiki/Calibration-Storage.md`
- `wiki/Calibration.md`
- `wiki/Climate-Engine.md`
- `wiki/Connector-Pinout.md`
- `wiki/Cooling-Safety.md`
- `wiki/Critical-Room.md`
- `wiki/Dew-Point-Margin.md`
- `wiki/Dew-Point.md`
- `wiki/Esphome.md`
- `wiki/FAQ.md`
- `wiki/Fail-Safe-Test.md`
- `wiki/Fail-Safe.md`
- `wiki/Hardware-Classic-Sensor.md`
- `wiki/Hardware-ESP-Sensor.md`
- `wiki/Hardware-Fake-Sensor.md`
- `wiki/Helpers.md`
- `wiki/Home-Assistant.md`
- `wiki/Home.md`
- `wiki/Humidity-Output.md`
- `wiki/Idm-Input-Test.md`
- `wiki/Knx.md`
- `wiki/Kty-Emulation.md`
- `wiki/Measurement-Template.md`
- `wiki/Modbus-GLT.md`
- `wiki/Modbus-Tcp.md`
- `wiki/Mqtt.md`
- `wiki/Native-ESP-IDF.md`
- `wiki/Ordering.md`
- `wiki/Original-Sensor-Test.md`
- `wiki/Original-Sensor.md`
- `wiki/Pipe-Sensor.md`
- `wiki/Power-Input.md`
- `wiki/Roadmap.md`
- `wiki/Sensor-Fusion.md`
- `wiki/Source-Quality.md`
- `wiki/Stale-Data.md`
- `wiki/State-Machine.md`
- `wiki/Strategy-Critical-Margin.md`
- `wiki/Strategy-Max-Humidity.md`
- `wiki/Strategy-Weighted.md`
- `wiki/Test-Points.md`
- `wiki/Thermal-Test.md`
- `wiki/Troubleshooting.md`
- `wiki/Validation.md`
- `wiki/Watchdog.md`
- `wiki/_Sidebar.md`
- `work-packages/WP01-hardware/README.md`
- `work-packages/WP02-firmware/README.md`
- `work-packages/WP03-home-assistant/README.md`
- `work-packages/WP04-documentation/README.md`
- `work-packages/WP05-validation/README.md`

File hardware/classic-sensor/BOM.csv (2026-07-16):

Ref | Qty | Part | Suggested
U1 | 1 | 24V→5V regulator | TPS54202/LMR16006
U2 | 1 | Controller | ATtiny1616
U3 | 1 | Humidity sensor | SHT45
U4 | 1 | DAC | MCP4725
U5 | 1 | Op amp | OPA197
RTH1 | 1 | Temperature sensor | KTY81-210
J1 | 1 | 4-pin terminal | 3.5mm
D1 | 1 | TVS | SMBJ30A

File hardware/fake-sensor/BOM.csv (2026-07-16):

Ref | Qty | Part | Suggested part | Purpose
U1 | 1 | 24V→5V buck | LMR16006/TPS54202 | ESP supply from IDM 24V
U2 | 1 | ESP32 module | ESP32-C3-MINI-1-N4 | ESPHome / Wi-Fi
U3 | 1 | 12-bit DAC | MCP4725A0T-E/CH | Humidity command
U4 | 1 | Op amp | OPA197IDBVR | 0–10V gain stage
U5 | 1 | Dual digital potentiometer | AD5242BRUZ10 | KTY81-210 resistance emulation
U6 | 1 | 3.3V regulator | AP2112K-3.3 | ESP supply
D1 | 1 | TVS | SMBJ30A | 24V transient protection
Q1 | 1 | Reverse-polarity MOSFET | AO3407A or suitable | Input protection
J1 | 1 | 4-pin terminal | 3.5mm pitch | IDM original connector signals
R/C | var. | Precision resistors/capacitors | 0.1% where noted | Gain and filtering

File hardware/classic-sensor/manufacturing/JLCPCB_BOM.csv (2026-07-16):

Comment | Designator | Footprint | LCSC Part Number | Status
24V regulator | U1 | TBD | TBD | Footprint and regulator not frozen
Controller | U2 | TBD | TBD | Variant dependent
DAC | U3 | TBD | TBD | Verify selected package
Op amp | U4 | TBD | TBD | Verify supply/output swing
Terminal | J1 | TBD | TBD | Match enclosure and wiring

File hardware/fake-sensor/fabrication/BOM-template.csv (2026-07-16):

Comment | Designator | Footprint | LCSC Part # | Status
Populate after freeze |  |  |  | WIP

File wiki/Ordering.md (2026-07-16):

# Ordering

Do not order until a fabrication release is tagged.

> Status: Work in progress. Contributions and measurements are welcome.

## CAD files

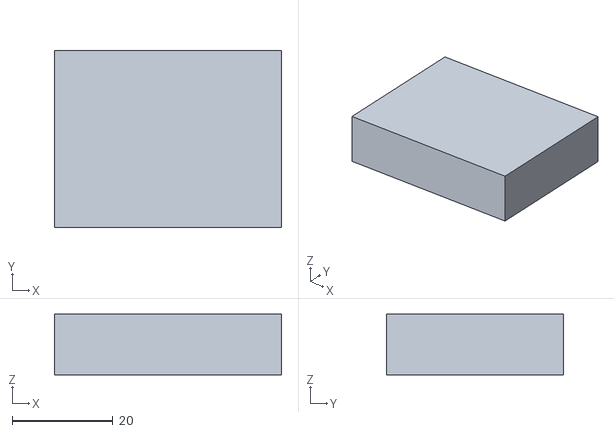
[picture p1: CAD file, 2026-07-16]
hardware/classic-sensor/enclosure/idm-roomsensor-classic_lid.stl
45.0 x 35.0 x 12.0

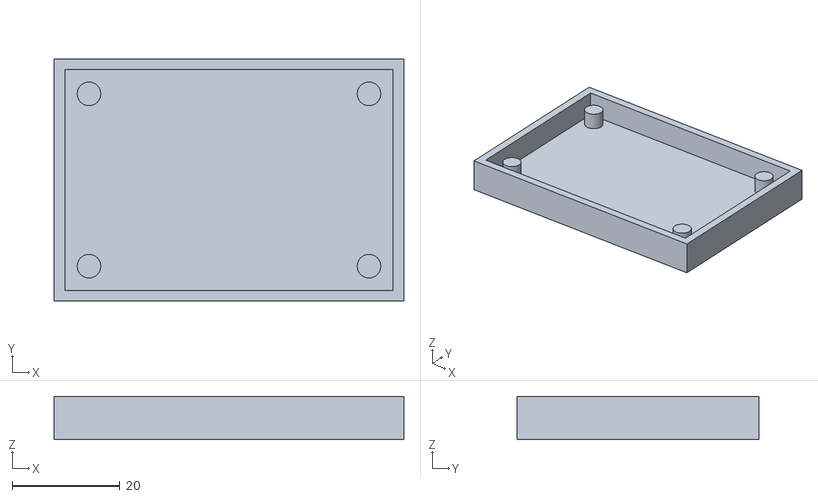
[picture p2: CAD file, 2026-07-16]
hardware/esp-sensor/enclosure/idm-roomsensor-esp_base.stl
65.0 x 45.0 x 8.00

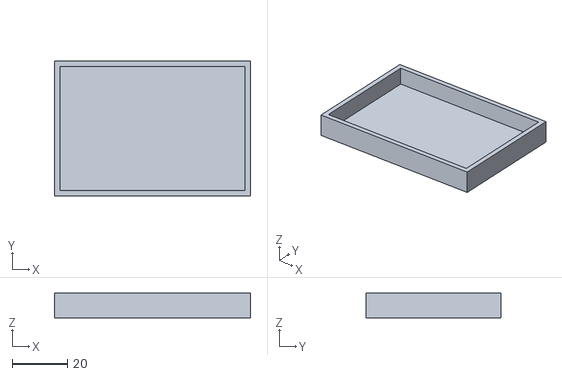
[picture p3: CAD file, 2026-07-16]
hardware/fake-sensor/enclosure/idm_fake_sensor_base.stl
71.0 x 49.0 x 9.00

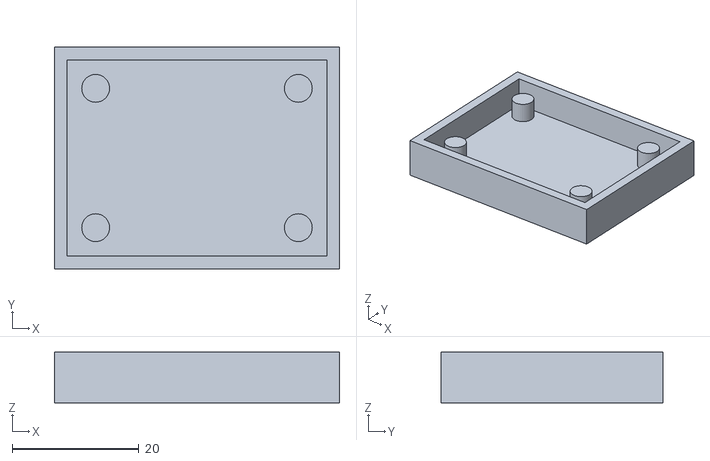
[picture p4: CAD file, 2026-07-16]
hardware/classic-sensor/enclosure/idm-roomsensor-classic_base.stl
45.0 x 35.0 x 8.00

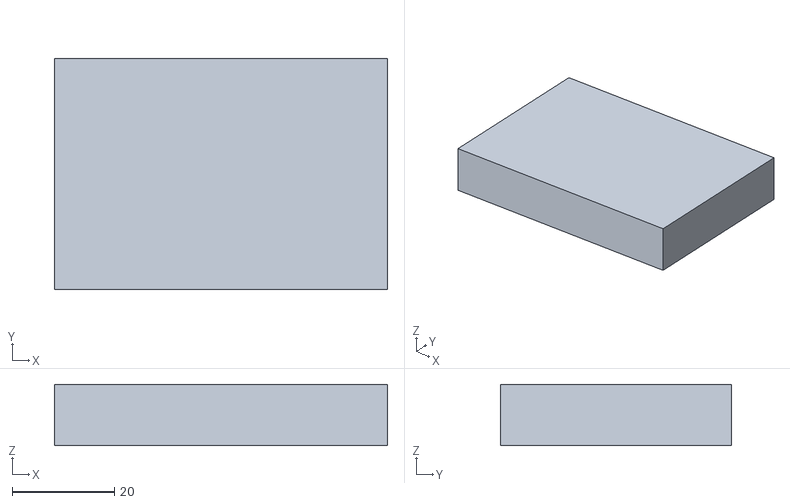
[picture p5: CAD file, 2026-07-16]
hardware/esp-sensor/enclosure/idm-roomsensor-esp_lid.stl
65.0 x 45.0 x 12.0

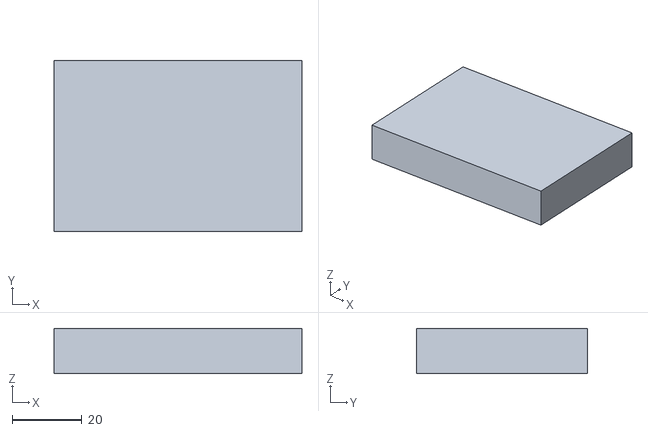
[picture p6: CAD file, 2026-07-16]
hardware/fake-sensor/enclosure/idm_fake_sensor_lid.stl
71.0 x 49.0 x 13.0

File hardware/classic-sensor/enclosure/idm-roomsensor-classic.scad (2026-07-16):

board_w=38; board_h=28; wall=2; clearance=1.5; base_d=8; lid_d=12;
outer_w=board_w+2*clearance+2*wall; outer_h=board_h+2*clearance+2*wall;
module rounded_box(w,h,d,r=2){minkowski(){cube([w-2*r,h-2*r,d],center=true);cylinder(r=r,h=.01,$fn=32);}}
module base(){difference(){translate([0,0,base_d/2])rounded_box(outer_w,outer_h,base_d,2);translate([0,0,base_d/2+wall])cube([outer_w-2*wall,outer_h-2*wall,base_d],center=true);}}
module lid(){difference(){translate([0,0,lid_d/2])rounded_box(outer_w,outer_h,lid_d,2);translate([0,0,lid_d/2-wall])cube([outer_w-2*wall,outer_h-2*wall,lid_d],center=true);for(y=[-outer_h/2+6:5:outer_h/2-6])translate([0,y,lid_d-wall/2])cube([outer_w-10,2.5,wall+2],center=true);}}
base();

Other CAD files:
hardware/esp-sensor/enclosure/idm-roomsensor-esp.scad
hardware/fake-sensor/enclosure/idm_fake_sensor.scad

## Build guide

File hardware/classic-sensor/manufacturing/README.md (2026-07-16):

# classic-sensor manufacturing status

**NOT RELEASED FOR FABRICATION.** These files are templates for community review. Gerbers generated from unverified routing must not be treated as production data.

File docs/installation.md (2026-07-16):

# Installation und Sensorposition

Für eine Wohnung mit ungefähr 100 m² sollte ein einzelner echter Raumsensor in einem repräsentativen Wohnbereich montiert werden:

- an einer Innenwand,
- ungefähr 1,2 bis 1,5 m über dem Boden,
- mit freier Luftzirkulation,
- nicht direkt neben Fenstern oder Türen,
- nicht in direkter Sonne,
- nicht über Wärmequellen,
- nicht in Küche oder Bad.

Für die Kühlung ist der Raum entscheidend, der hinsichtlich Temperatur und Feuchte am kritischsten ist. Der Fake Sensor kann deshalb mehrere Home-Assistant-Sensoren auswerten und den ungünstigsten Raum an die IDM weitergeben.

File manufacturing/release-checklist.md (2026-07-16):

# Fabrication release checklist

- [ ] Exact BOM parts frozen
- [ ] Manufacturer datasheets archived by URL and revision
- [ ] Footprints checked against land-pattern drawings
- [ ] ERC clean or every exception documented
- [ ] DRC clean
- [ ] Copper current and clearance review
- [ ] Analog-output SPICE/bench validation
- [ ] 3D enclosure interference check
- [ ] Gerber visual inspection
- [ ] BOM/CPL import preview checked at manufacturer
- [ ] Prototype ordered as clearly marked engineering sample

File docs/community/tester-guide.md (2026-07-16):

# Tester Guide

Testers should publish raw data and distinguish bench from real-installation results.

## Status

- [ ] Reviewed
- [ ] Bench tested
- [ ] Real-device tested

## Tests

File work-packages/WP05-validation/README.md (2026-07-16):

# Validation

- [ ] Original sensor
- [ ] IDM input
- [ ] 0–10 V calibration
- [ ] KTY validation
- [ ] Fail-safe
- [ ] Thermal
- [ ] Real installation

Results must include conditions, equipment and raw data.

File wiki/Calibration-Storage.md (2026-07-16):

# Calibration Storage

See `docs/firmware/calibration-storage.md`.

- [x] CRC, ranges, read-back and V1 migration unit tested
- [x] ESPHome and native ESP-IDF integrations compile tested
- [ ] Power-interruption bench tested
- [ ] Real-device calibrated
- [ ] Community reviewed

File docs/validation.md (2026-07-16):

# Validation plan

## Gate A — Documentation review
- Confirm exact IDM model and wiring diagram.
- Confirm GLT register availability and writable metadata.
- Review every assumption in the schematics.

## Gate B — Bench electrical tests
- 14, 24 and 30 V supply tests.
- Reverse polarity and transient protection tests.
- 0–10 V output at 0, 25, 50, 75 and 100 % commands.
- Load tests at 10 kΩ, 5 kΩ and measured IDM input impedance.
- KTY resistance output over -20…60 °C equivalent range.
- Startup, brownout, Wi-Fi loss and I²C fault injection.

## Gate C — IDM input characterization
- Measure KTY input open-circuit voltage.
- Use a calibrated resistance decade to map displayed temperature.
- Verify output-ground topology.
- Confirm humidity scaling using a precision voltage source.

## Gate D — Controlled commissioning
- Independent pipe dew-point switch installed and tested.
- Begin in heating-only observation mode.
- Enable cooling under supervision with data logging.
- Verify safe response to stale values and communications loss.

No checkbox may be marked verified without a dated measurement report.

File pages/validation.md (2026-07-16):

# Validation

Validation is divided into bench measurements, prototype tests and real-IDM commissioning. Raw measurements and instrument details must be attached to every verification claim.

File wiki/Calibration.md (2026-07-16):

# Calibration

0–10 V and KTY emulation calibration workflow.

> Status: Work in progress. Contributions and measurements are welcome.

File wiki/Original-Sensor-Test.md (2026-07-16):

# Original Sensor Test

See `docs/validation/original-sensor-test.md`.

- [ ] Community reviewed
- [ ] Validated

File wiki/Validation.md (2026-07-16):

# Validation

Bench and real-device test matrix.

> Status: Work in progress. Contributions and measurements are welcome.

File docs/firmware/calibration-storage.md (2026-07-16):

# Calibration Storage

The ESPHome analog bridge stores its active transfer-function calibration in
the platform preference backend (ESP32 NVS). Configuration values remain the
factory defaults and are never overwritten.

## Stored values

The current version-2 record contains:

| Field | Accepted range |
|---|---:|
| Humidity DAC minimum code | 0…4094 |
| Humidity DAC maximum code | 1…4095 and greater than the minimum |
| Temperature-network minimum resistance | 100…50,000 Ω |
| Temperature-network maximum resistance | 100…50,000 Ω and greater than the minimum |
| Temperature code inversion | true/false |

Each record also carries a fixed magic value, format version, record size,
flags and an IEEE CRC-32 over every preceding byte. The ESPHome preference ID
is configured separately from the record version so the component can read a
legacy record and write the migrated current record without ambiguity.

## Boot and failure behaviour

1. Load and validate a version-2 record.
2. If no version-2 record exists, attempt the documented version-1 migration.
3. Reject unknown versions, sizes, flags, non-finite values, invalid ranges or
   CRC mismatches.
4. On rejection, use the compiled factory values and publish
   `invalid_using_factory`.
5. Never fall back from a present but invalid current record to an older
   record, because that could silently resurrect stale calibration.

The first boot without stored data uses factory values and publishes
`factory_defaults`. A successful migration is immediately rewritten as a
version-2 record. A failed migration write remains visible as
`migration_save_failed`.

## Updates and reset

`idm_bridge.set_calibration` validates the complete calibration atomically,
writes it to NVS, reads it back and only then activates it. Invalid or
unconfirmed writes therefore cannot partially change the active transfer
function.

`idm_bridge.reset_calibration` persists the values from the YAML configuration
and activates them. It does not erase unrelated ESPHome preferences.

The following diagnostics are available under `analog_output`:

- `calibration_status`
- `calibration_version`
- `calibration_using_factory`

Keep `calibration_preference_id` stable when renaming the component ID. A new
preference ID intentionally starts with factory defaults.

## Migration contract

Version 1 stored humidity as `DAC code = offset + gain × RH[%]`, plus the two
temperature-resistance endpoints and the inversion flag. Migration converts
that representation to the version-2 minimum and maximum DAC codes, validates
the result, then writes a new version-2 record.

## Verification status

- [x] Format, CRC, range and migration unit tests
- [x] Compiled against the pinned ESPHome/ESP32 target
- [ ] Power-interruption bench test
- [ ] Real-device calibration test

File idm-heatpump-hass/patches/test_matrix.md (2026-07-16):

# Test matrix

Circuits A–G, 15–30 °C temperature limits, 0–100 % humidity limits, invalid
circuit, missing/read-only registers, non-finite values, optional humidity and
no partial write on preflight validation failure.

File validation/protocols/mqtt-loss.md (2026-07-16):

# MQTT loss and restart test

Status: NOT RUN

This test verifies discovery replay, retained availability, command safety and
the independence of the local fail-safe state machine from the broker.

## Equipment and setup

- Device flashed from one of the supported ESPHome MQTT manifests.
- MQTT enabled with a unique topic prefix and a dedicated test account.
- MQTT broker with retained-message inspection and connection logs.
- Clean MQTT subscriber that can show QoS and retained flags.
- Home Assistant test instance for discovery checks.
- Means to interrupt Wi-Fi without gracefully shutting down the device.
- For the analog bridge: isolated load or measurement fixture; do not connect
  unverified outputs to a heat pump.

Record firmware revision, broker/version, Home Assistant version, device MAC,
topic prefix, configured stale timeout and broker keepalive behaviour.

## Procedure

1. Clear retained messages below `<prefix>/command/#`.
2. Start the broker, subscriber and device.
3. Verify retained `<prefix>/availability=online`, retained entity state and a
   retained `<prefix>/diagnostics/state` payload matching the applicable JSON
   schema.
4. Record every Home Assistant entity unique ID and object ID.
5. Restart Home Assistant with the device still online. Verify that the same
   entities and current retained states reappear.
6. Restart the device. Verify that the same entities reappear and availability
   changes back to `online`.
7. Interrupt the device network without a graceful shutdown. Keep the device
   powered.
8. While offline, publish a QoS 1, non-retained command and confirm that the
   local bridge reaches its configured stale fallback independently.
9. Verify that the broker publishes the retained Last-Will state
   `<prefix>/availability=offline`.
10. Restore the network. Verify `online`, a fresh diagnostic payload and that
    the command published while offline is not applied.
11. Publish an invalid atomic climate command and verify safe fallback plus
    `command_source=mqtt_invalid` and `command_quality=0`.
12. Inspect the broker and confirm there are no retained command messages.

## Acceptance criteria

- Discovery payloads and state payloads are retained; command payloads are not.
- Entity unique IDs and object IDs are identical across Home Assistant and
  device restarts.
- Abrupt connection loss becomes visible as retained `offline` no later than
  the broker's documented keepalive timeout (normally at most 45 seconds for
  the configured 30-second keepalive).
- Reconnect publishes `online` and fresh diagnostics within 10 seconds after
  MQTT connection establishment.
- A command published while the clean-session client is offline is not
  replayed after reconnect.
- Broker loss does not reboot the device or suppress the local stale timeout,
  output-fault handling or safe fallback.
- Invalid commands never reach the normal active state.

Save broker logs, Home Assistant screenshots, subscriber output and all timing
observations. Enter observations in `validation/raw-data/mqtt-loss.csv`; keep
the result status `NOT RUN` until real hardware and a real broker were used.

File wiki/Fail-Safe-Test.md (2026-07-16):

# Fail Safe Test

See `docs/validation/fail-safe-test.md`.

- [ ] Community reviewed
- [ ] Validated

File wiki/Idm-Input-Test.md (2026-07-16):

# Idm Input Test

See `docs/validation/idm-input-test.md`.

- [ ] Community reviewed
- [ ] Validated

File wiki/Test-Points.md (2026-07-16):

# Test Points

See `docs/hardware/test-points.md`.

- [ ] Community reviewed
- [ ] Validated

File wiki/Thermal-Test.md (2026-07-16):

# Thermal Test

See `docs/validation/thermal-test.md`.

- [ ] Community reviewed
- [ ] Validated

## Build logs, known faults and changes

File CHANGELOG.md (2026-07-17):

# Changelog

## Unreleased
### Security and safety hardening (fail-closed)
- Made MQTT credentials fail-closed: device entry points ship sentinel placeholders and `tools/check_esphome.py` refuses to validate while they remain; documented the MQTT threat model and TLS/mTLS options.
- Made the local web UI fail-closed: the web server disables itself at runtime if `web_password` is still the shipped placeholder.
- Native diagnostics endpoint now requires a bearer token when `IDM_API_TOKEN` is set, and redacts sensor/command-provenance fields when no token is configured.
- OTA is now health-gated: a pending image is confirmed only after a configurable health window, never blindly at boot; added an optional `IDM_OTA_ALLOWED_HOST` allowlist.
- Added a stale/availability interlock and a run-time hysteresis guard to the cooling-inhibit blueprint.
- Rewrote the fake-sensor automation to select by dew point (not relative humidity) and to fail closed when no room has usable data.
### Correctness and robustness
- Added an optional command-quality gate to the ESPHome bridge (default 0, backward compatible) plus an `INVALID_QUALITY` error.
- Enforced `min < max` on the humidity DAC code range; the legacy float-output path now respects output readiness.
- Removed the duplicate `tick()` call in the native main loop and added Wi-Fi reconnect exponential backoff.
- Deleted the dead `failsafe.h` and rewrote the state-machine documentation to match the real `BridgeState` machine.
- Regenerated the 20 room templates via `tools/generate_room_examples.py` with `unique_id`, `device_class`, `state_class` and an availability template.
### CI, tooling and quality gate
- Added `permissions: contents: read`, concurrency cancellation, a g++ presence guard, and extended path filters to the workflows.
- Pinned every GitHub Action to a commit SHA; added a pinned `.github/requirements-ci.txt` with pip caching.
- Pinned README safety warnings to stable HTML-comment sentinels instead of brittle substring matching.
- Aligned `dew_point.py` with the C++ input domain (`t <= -243.12` guard).
- Added JSON-Schema validation (`check_schema` + representative payloads) for every MQTT schema.
### Documentation and hygiene
- Repaired the broken README Safety/Validation links.
- Documented the ESP-IDF OTA allowlist/health behaviour and diagnostics redaction.
- Documented the `check_esphome.py` syntax-only vs `--compile` distinction.

## 0.2.0 — Developer Edition
- Fixed critical-room selection to use the highest calculated dew point instead of humidity alone.
- Added `last_reported`-based stale-input detection and conservative fallback values.
- Kept the Home Assistant package compatible with released `idm-heatpump-hass` v0.8.2 via `write_register`.
- Aligned the `set_external_climate` reference with the native service now present on upstream main.
- Made the cooling-inhibit blueprint executable with configurable hysteresis actions.
- Made the critical-room and standalone stale-data blueprints executable.
- Added transition, fallback and blueprint-output regression tests.
- Added climate selection, source-age, fallback and publish diagnostics.
- Added restart, tie, unavailable-input and output-clamping regression tests.
- Pinned ESPHome 2026.6.5 and added manifest-based configuration and firmware builds.
- Migrated device names, OTA configuration and fallback captive portals to the pinned ESPHome release.
- Implemented the `idm_bridge` lifecycle, validation, timeout fallback, latched output faults and diagnostics.
- Replaced fake-sensor output placeholders with compiled MCP4725 and AD5242 drivers, atomic fallback handling and output diagnostics.
- Added versioned, CRC-protected calibration persistence with range validation, V1 migration, read-back verification and factory reset.
- Expanded native unit coverage for dew point, KTY interpolation, value quality, fallback transitions, clamping and calibration transforms.
- Rejected invalid embedded dew-point humidity inputs instead of silently clamping them to a potentially unsafe value.
- Added deterministic MQTT discovery, retained availability/state, versioned diagnostics, atomic command validation and broker-loss contract tests.
- Added an authenticated, fully local ESPHome web UI for status, command visibility, bounded calibration, confirmation-gated apply/reset actions and versioned diagnostic export.
- Replaced the native ESP-IDF dew-point demonstration with a build-tested bridge runtime providing real MCP4725/AD5242 I/O, quality and stale fallback, CRC-protected NVS calibration, Wi-Fi REST diagnostics, task watchdog, brownout protection and confirmation-gated HTTPS OTA.
- Synchronized firmware status and remaining physical validation gates across the README, project summary, work package, Docsify pages and Wiki.
- Added executable service-contract, dew-point, YAML and repository checks to CI.
- Fixed repository YAML lint configuration.

## Developer Edition 0.1.0 — WIP
- Added Docsify Pages and Wiki source.
- Added validation and community test plans.
- Added climate-engine examples.
- Added proposed `set_external_climate` implementation and test skeleton.
- Added manufacturing templates explicitly marked not released.

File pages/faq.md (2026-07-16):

# FAQ

**Can I order the PCBs now?** No. They are WIP prototypes. **Can GLT replace analog hardware?** Possibly, but the exact IDM configuration and cooling behavior must be verified.

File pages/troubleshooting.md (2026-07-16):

# Troubleshooting

If values are implausible, disconnect the prototype, restore the original safety chain and verify supply, ground reference, output voltage and configured GLT ownership.

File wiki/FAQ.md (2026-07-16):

# FAQ

Frequently asked questions.

> Status: Work in progress. Contributions and measurements are welcome.

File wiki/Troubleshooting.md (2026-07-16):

# Troubleshooting

Diagnostic steps and safe rollback.

> Status: Work in progress. Contributions and measurements are welcome.

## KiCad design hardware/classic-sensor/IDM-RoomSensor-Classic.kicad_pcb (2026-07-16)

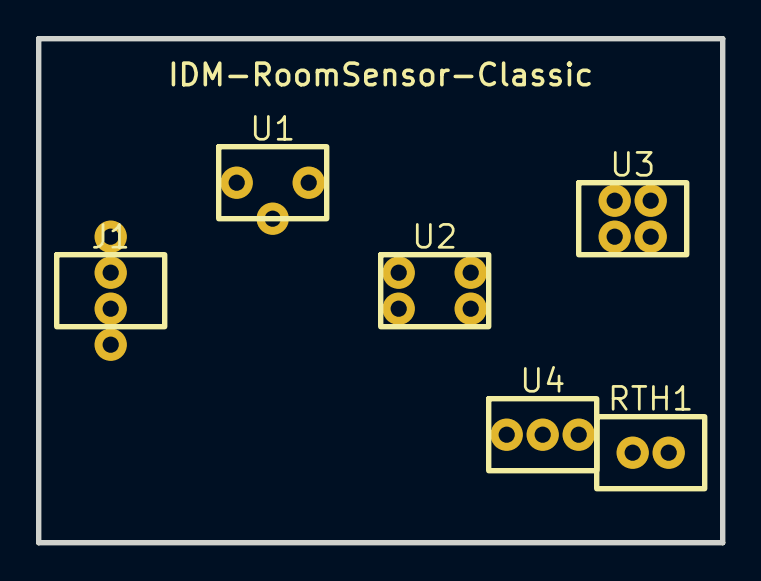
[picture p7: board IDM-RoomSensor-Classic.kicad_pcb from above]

Board: 2 copper layers, 38.0 x 28.0 mm, 6 parts (0 on the bottom side), 7 nets, no tracks yet.

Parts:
J1: IDM_4PIN
RTH1: KTY81-210
U1: BUCK_24V_5V
U2: ATTINY1616
U3: SHT45
U4: MCP4725_OPA197

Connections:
+5V: U1.2, U2.1, U3.1, U4.1
+24V: J1.2, U1.1
GND: J1.3, RTH1.2, U1.3, U2.2, U3.2, U4.2
I2C_SCL: U2.4, U3.4
I2C_SDA: U2.3, U3.3
RH_0_10V: J1.4, U4.3
TEMP_KTY: J1.1, RTH1.1

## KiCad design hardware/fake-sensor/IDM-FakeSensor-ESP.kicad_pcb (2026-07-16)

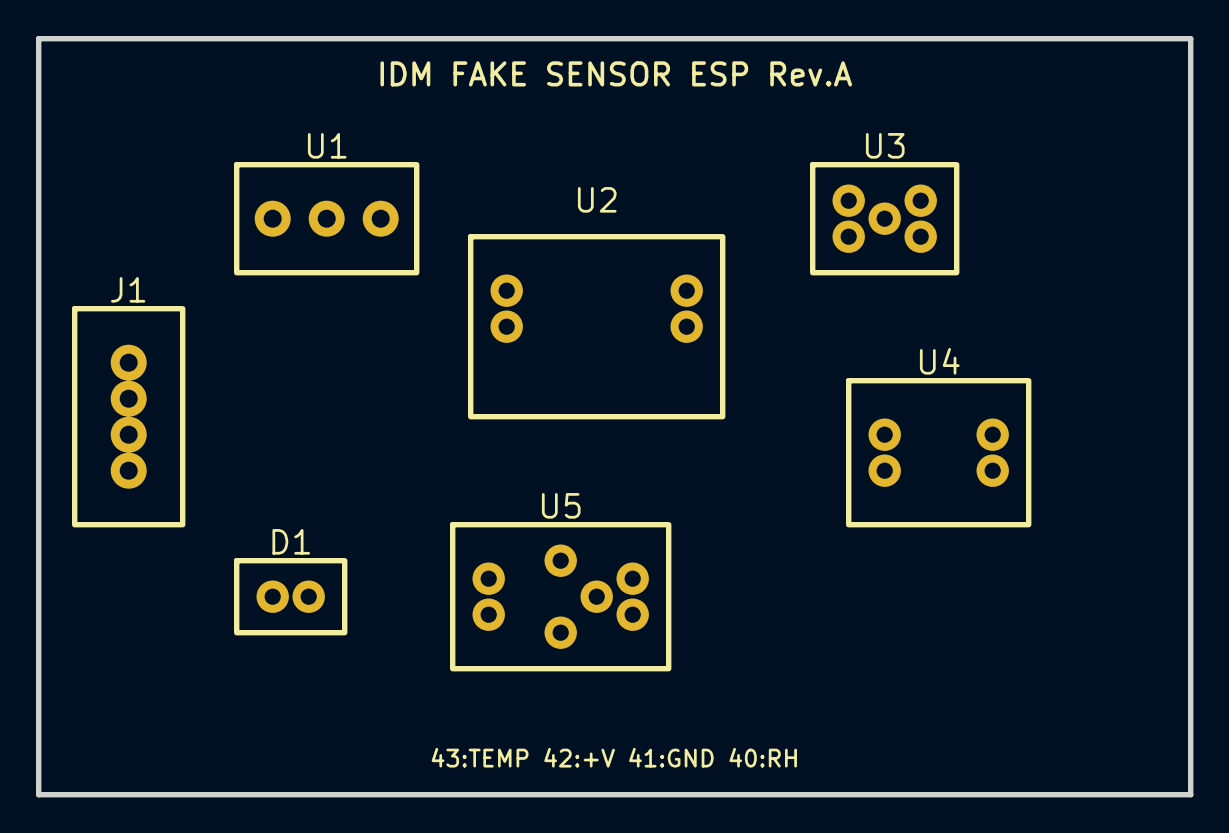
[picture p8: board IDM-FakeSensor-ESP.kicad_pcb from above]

Board: 2 copper layers, 64.0 x 42.0 mm, 7 parts (0 on the bottom side), 8 nets, no tracks yet.

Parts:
D1: SMBJ30A; TVS_INPUT
J1: IDM; TERM_4P
U1: 24V_TO_5V; BUCK
U2: ESP32-C3-MINI-1; ESP32_C3_MINI
U3: MCP4725
U4: OPA197_GAIN; OPA197_0_10V
U5: AD5242BRUZ10; AD5242_DIGIPOT

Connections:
+3V3: U2.1, U3.1, U5.1
+24V: D1.1, J1.2, U1.1, U4.3
DAC_RAW: U3.5, U4.1
GND: D1.2, J1.3, U1.2, U2.2, U3.2, U4.2, U5.2
I2C_SCL: U2.4, U3.4, U5.4
I2C_SDA: U2.3, U3.3, U5.3
RH_0_10V: J1.4, U4.4
TEMP_A: J1.1, U5.5

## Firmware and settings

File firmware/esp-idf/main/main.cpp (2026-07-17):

// SPDX-License-Identifier: MIT
// SPDX-FileCopyrightText: 2026 Xerolux

#include <atomic>
#include <cmath>
#include <cstdint>
#include <cstdio>
#include <cstdlib>
#include <cstring>
#include <string>

#include "cJSON.h"
#include "driver/i2c_master.h"
#include "esp_app_desc.h"
#include "esp_crt_bundle.h"
#include "esp_err.h"
#include "esp_event.h"
#include "esp_http_client.h"
#include "esp_http_server.h"
#include "esp_https_ota.h"
#include "esp_log.h"
#include "esp_netif.h"
#include "esp_ota_ops.h"
#include "esp_system.h"
#include "esp_task_wdt.h"
#include "esp_timer.h"
#include "esp_wifi.h"
#include "freertos/FreeRTOS.h"
#include "freertos/semphr.h"
#include "freertos/task.h"
#include "nvs.h"
#include "nvs_flash.h"
#include "sdkconfig.h"

#include "idm_calibration_storage_core.h"
#include "native_runtime.h"

namespace {

using esphome::idm_bridge::CalibrationLoadStatus;
using esphome::idm_bridge::CalibrationRecordV1;
using esphome::idm_bridge::CalibrationRecordV2;
using esphome::idm_bridge::CalibrationStorageCore;
using esphome::idm_bridge::IdmAnalogCalibration;
using esphome::idm_bridge::calibration_equal;
using esphome::idm_bridge::valid_calibration;
using idm::native::NativeDiagnostics;
using idm::native::NativeOutput;
using idm::native::NativeRuntime;
using idm::native::NativeRuntimeConfig;

constexpr char TAG[] = "idm_native";
constexpr char NVS_NAMESPACE[] = "idm_native";
constexpr char NVS_CALIBRATION_V2_KEY[] = "cal_v2";
constexpr char NVS_CALIBRATION_V1_KEY[] = "cal_v1";
constexpr size_t HTTP_BODY_LIMIT = 768;
constexpr uint32_t OUTPUT_RETRY_MS = 1000;
constexpr uint32_t I2C_RETRY_MS = 5000;
#ifdef CONFIG_IDM_FACTORY_TEMPERATURE_CODE_INVERTED
constexpr bool FACTORY_TEMPERATURE_CODE_INVERTED = true;
#else
constexpr bool FACTORY_TEMPERATURE_CODE_INVERTED = false;
#endif

struct OutputHardware {
  i2c_master_bus_handle_t bus{nullptr};
  i2c_master_dev_handle_t humidity{nullptr};
  i2c_master_dev_handle_t temperature{nullptr};
  bool ready{false};
};

NativeRuntime s_runtime;
SemaphoreHandle_t s_runtime_mutex{nullptr};
OutputHardware s_output_hardware;
std::atomic<bool> s_wifi_connected{false};
std::atomic<bool> s_ota_running{false};
httpd_handle_t s_http_server{nullptr};
bool s_nvs_ready{false};
char s_output_error[64]{"not_initialized"};
char s_ota_status[32]{"idle"};
uint32_t s_next_output_attempt_ms{0};
uint32_t s_next_i2c_attempt_ms{0};

class RuntimeGuard {
 public:
  RuntimeGuard() {
    if (s_runtime_mutex != nullptr)
      xSemaphoreTake(s_runtime_mutex, portMAX_DELAY);
  }

  ~RuntimeGuard() {
    if (s_runtime_mutex != nullptr)
      xSemaphoreGive(s_runtime_mutex);
  }

  RuntimeGuard(const RuntimeGuard &) = delete;
  RuntimeGuard &operator=(const RuntimeGuard &) = delete;
};

uint32_t now_ms() {
  return static_cast<uint32_t>(
      static_cast<uint64_t>(esp_timer_get_time()) / 1000ULL);
}

float configured_float(const char *value, float fallback) {
  if (value == nullptr)
    return fallback;
  char *end = nullptr;
  const float parsed = std::strtof(value, &end);
  if (end == value || *end != '\0' || !std::isfinite(parsed))
    return fallback;
  return parsed;
}

IdmAnalogCalibration factory_calibration() {
  return {
      static_cast<uint16_t>(CONFIG_IDM_FACTORY_HUMIDITY_CODE_MIN),
      static_cast<uint16_t>(CONFIG_IDM_FACTORY_HUMIDITY_CODE_MAX),
      configured_float(
          CONFIG_IDM_FACTORY_TEMPERATURE_RESISTANCE_MIN, 650.0f),
      configured_float(
          CONFIG_IDM_FACTORY_TEMPERATURE_RESISTANCE_MAX, 3000.0f),
      FACTORY_TEMPERATURE_CODE_INVERTED,
  };
}

void copy_status(char *destination, size_t size, const char *value) {
  if (destination == nullptr || size == 0)
    return;
  std::snprintf(destination, size, "%s", value != nullptr ? value : "unknown");
}

void set_output_error(const char *value) {
  RuntimeGuard guard;
  copy_status(s_output_error, sizeof(s_output_error), value);
}

void set_ota_status(const char *value) {
  RuntimeGuard guard;
  copy_status(s_ota_status, sizeof(s_ota_status), value);
}

bool initialize_nvs() {
  esp_err_t result = nvs_flash_init();
  if (result == ESP_ERR_NVS_NO_FREE_PAGES ||
      result == ESP_ERR_NVS_NEW_VERSION_FOUND) {
    ESP_LOGW(TAG, "NVS requires recovery; erasing partition");
    result = nvs_flash_erase();
    if (result == ESP_OK)
      result = nvs_flash_init();
  }
  if (result != ESP_OK) {
    ESP_LOGE(TAG, "NVS initialization failed: %s", esp_err_to_name(result));
    return false;
  }
  return true;
}

template<typename T>
bool read_nvs_record(nvs_handle_t handle, const char *key, T *value) {
  size_t size = sizeof(T);
  return nvs_get_blob(handle, key, value, &size) == ESP_OK &&
         size == sizeof(T);
}

bool persist_calibration(const IdmAnalogCalibration &calibration) {
  if (!s_nvs_ready || !valid_calibration(calibration))
    return false;

  nvs_handle_t handle;
  esp_err_t result =
      nvs_open(NVS_NAMESPACE, NVS_READWRITE, &handle);
  if (result != ESP_OK)
    return false;

  const CalibrationRecordV2 record =
      CalibrationStorageCore::make_record(calibration);
  result = nvs_set_blob(
      handle, NVS_CALIBRATION_V2_KEY, &record, sizeof(record));
  if (result == ESP_OK)
    result = nvs_commit(handle);

  CalibrationRecordV2 read_back{};
  size_t read_back_size = sizeof(read_back);
  if (result == ESP_OK) {
    result = nvs_get_blob(
        handle, NVS_CALIBRATION_V2_KEY, &read_back, &read_back_size);
  }
  nvs_close(handle);

  IdmAnalogCalibration decoded{};
  return result == ESP_OK && read_back_size == sizeof(read_back) &&
         CalibrationStorageCore::decode_record(read_back, &decoded) &&
         calibration_equal(decoded, calibration);
}

IdmAnalogCalibration load_calibration(
    const IdmAnalogCalibration &factory) {
  if (!s_nvs_ready)
    return factory;

  nvs_handle_t handle;
  if (nvs_open(NVS_NAMESPACE, NVS_READONLY, &handle) != ESP_OK)
    return factory;

  CalibrationRecordV2 current{};
  CalibrationRecordV1 legacy{};
  const bool has_current = read_nvs_record(
      handle, NVS_CALIBRATION_V2_KEY, &current);
  const bool has_legacy =
      !has_current &&
      read_nvs_record(handle, NVS_CALIBRATION_V1_KEY, &legacy);
  nvs_close(handle);

  const auto loaded = CalibrationStorageCore::load(
      factory, has_current, current, has_legacy, legacy);
  ESP_LOGI(
      TAG, "Calibration load status: %s",
      CalibrationStorageCore::status_name(loaded.status));

  if (loaded.migration_required) {
    if (persist_calibration(loaded.calibration)) {
      ESP_LOGI(TAG, "Migrated V1 calibration to V2");
    } else {
      ESP_LOGE(TAG, "Failed to persist migrated calibration");
    }
  } else if (
      loaded.status == CalibrationLoadStatus::INVALID_USING_FACTORY) {
    ESP_LOGW(TAG, "Invalid stored calibration; using factory values");
  }
  return loaded.calibration;
}

void release_output_hardware() {
  if (s_output_hardware.humidity != nullptr) {
    i2c_master_bus_rm_device(s_output_hardware.humidity);
    s_output_hardware.humidity = nullptr;
  }
  if (s_output_hardware.temperature != nullptr) {
    i2c_master_bus_rm_device(s_output_hardware.temperature);
    s_output_hardware.temperature = nullptr;
  }
  if (s_output_hardware.bus != nullptr) {
    i2c_del_master_bus(s_output_hardware.bus);
    s_output_hardware.bus = nullptr;
  }
  s_output_hardware.ready = false;
}

bool initialize_output_hardware() {
  if (s_output_hardware.ready)
    return true;
  release_output_hardware();

  i2c_master_bus_config_t bus_config{};
  bus_config.i2c_port = I2C_NUM_0;
  bus_config.sda_io_num =
      static_cast<gpio_num_t>(CONFIG_IDM_I2C_SDA_GPIO);
  bus_config.scl_io_num =
      static_cast<gpio_num_t>(CONFIG_IDM_I2C_SCL_GPIO);
  bus_config.clk_source = I2C_CLK_SRC_DEFAULT;
  bus_config.glitch_ignore_cnt = 7;
  bus_config.flags.enable_internal_pullup = true;

  esp_err_t result =
      i2c_new_master_bus(&bus_config, &s_output_hardware.bus);
  if (result != ESP_OK) {
    ESP_LOGE(TAG, "I2C bus initialization failed: %s",
             esp_err_to_name(result));
    set_output_error("i2c_bus_init_failed");
    release_output_hardware();
    return false;
  }

  i2c_device_config_t humidity_config{};
  humidity_config.dev_addr_length = I2C_ADDR_BIT_LEN_7;
  humidity_config.device_address = CONFIG_IDM_HUMIDITY_I2C_ADDRESS;
  humidity_config.scl_speed_hz = 100000;
  result = i2c_master_bus_add_device(
      s_output_hardware.bus, &humidity_config,
      &s_output_hardware.humidity);
  if (result != ESP_OK) {
    ESP_LOGE(TAG, "MCP4725 registration failed: %s",
             esp_err_to_name(result));
    set_output_error("humidity_dac_init_failed");
    release_output_hardware();
    return false;
  }

  i2c_device_config_t temperature_config{};
  temperature_config.dev_addr_length = I2C_ADDR_BIT_LEN_7;
  temperature_config.device_address =
      CONFIG_IDM_TEMPERATURE_I2C_ADDRESS;
  temperature_config.scl_speed_hz = 100000;
  result = i2c_master_bus_add_device(
      s_output_hardware.bus, &temperature_config,
      &s_output_hardware.temperature);
  if (result != ESP_OK) {
    ESP_LOGE(TAG, "AD5242 registration failed: %s",
             esp_err_to_name(result));
    set_output_error("temperature_digipot_init_failed");
    release_output_hardware();
    return false;
  }

  s_output_hardware.ready = true;
  set_output_error("none");
  ESP_LOGI(TAG, "I2C analog outputs initialized");
  return true;
}

bool write_output(const NativeOutput &output) {
  if (!s_output_hardware.ready)
    return false;

  const uint16_t humidity_code = output.humidity_dac_code & 0x0FFF;
  const uint8_t humidity_data[] = {
      0x40,
      static_cast<uint8_t>(humidity_code >> 4),
      static_cast<uint8_t>((humidity_code & 0x0F) << 4),
  };
  const uint8_t temperature_data[] = {
      0x00,
      output.temperature_digipot_code,
  };

  const esp_err_t humidity_result = i2c_master_transmit(
      s_output_hardware.humidity, humidity_data, sizeof(humidity_data),
      100);
  const esp_err_t temperature_result = i2c_master_transmit(
      s_output_hardware.temperature, temperature_data,
      sizeof(temperature_data), 100);

  if (humidity_result != ESP_OK && temperature_result != ESP_OK) {
    set_output_error("humidity_and_temperature_write_failed");
  } else if (humidity_result != ESP_OK) {
    set_output_error("humidity_dac_write_failed");
  } else if (temperature_result != ESP_OK) {
    set_output_error("temperature_digipot_write_failed");
  } else {
    set_output_error("none");
    return true;
  }

  ESP_LOGE(
      TAG, "Analog output write failed: humidity=%s temperature=%s",
      esp_err_to_name(humidity_result),
      esp_err_to_name(temperature_result));
  return false;
}

void record_output_result(bool success) {
  RuntimeGuard guard;
  s_runtime.record_output_result(success);
}

bool apply_outputs_once(uint32_t current_ms) {
  (void) current_ms;
  NativeOutput output{};
  bool dirty = false;
  {
    RuntimeGuard guard;
    // tick() is driven by the main loop (every 100 ms) so stale-timeout
    // transitions are detected promptly; do not re-tick here. This function
    // only reads whether a fresh output write is pending.
    dirty = s_runtime.output_dirty();
    if (dirty)
      output = s_runtime.desired_output();
  }
  if (!dirty)
    return true;

  const bool success =
      initialize_output_hardware() && write_output(output);
  record_output_result(success);
  return success;
}

void add_number_or_null(cJSON *root, const char *name, float value) {
  if (std::isfinite(value))
    cJSON_AddNumberToObject(root, name, value);
  else
    cJSON_AddNullToObject(root, name);
}

esp_err_t send_json(httpd_req_t *request, cJSON *root) {
  char *payload = cJSON_PrintUnformatted(root);
  cJSON_Delete(root);
  if (payload == nullptr)
    return httpd_resp_send_err(
        request, HTTPD_500_INTERNAL_SERVER_ERROR,
        "JSON serialization failed");
  httpd_resp_set_type(request, "application/json");
  const esp_err_t result =
      httpd_resp_send(request, payload, HTTPD_RESP_USE_STRLEN);
  std::free(payload);
  return result;
}

esp_err_t send_error(
    httpd_req_t *request, const char *status, const char *error) {
  httpd_resp_set_status(request, status);
  cJSON *root = cJSON_CreateObject();
  cJSON_AddStringToObject(root, "error", error);
  return send_json(request, root);
}

bool constant_time_equal(
    const std::string &left, const std::string &right) {
  const size_t maximum =
      left.size() > right.size() ? left.size() : right.size();
  unsigned int difference =
      static_cast<unsigned int>(left.size() ^ right.size());
  for (size_t index = 0; index < maximum; index++) {
    const unsigned char left_value =
        index < left.size()
            ? static_cast<unsigned char>(left[index])
            : 0;
    const unsigned char right_value =
        index < right.size()
            ? static_cast<unsigned char>(right[index])
            : 0;
    difference |= left_value ^ right_value;
  }
  return difference == 0;
}

bool authorize_mutation(httpd_req_t *request) {
  const std::string token = CONFIG_IDM_API_TOKEN;
  if (token.empty()) {
    send_error(
        request, "503 Service Unavailable",
        "mutating API disabled until IDM_API_TOKEN is configured");
    return false;
  }

  char header[384]{};
  if (httpd_req_get_hdr_value_str(
          request, "Authorization", header, sizeof(header)) != ESP_OK) {
    httpd_resp_set_hdr(request, "WWW-Authenticate", "Bearer");
    send_error(request, "401 Unauthorized", "missing bearer token");
    return false;
  }

  const std::string expected = "Bearer " + token;
  if (!constant_time_equal(header, expected)) {
    httpd_resp_set_hdr(request, "WWW-Authenticate", "Bearer");
    send_error(request, "401 Unauthorized", "invalid bearer token");
    return false;
  }
  return true;
}

// Outcome of a diagnostics authorization check.
enum class DiagnosticsAuth {
  kFull,         // token configured and request authorized: publish everything
  kRedacted,     // token unset: publish operational fields, redact sensor data
  kBlocked,      // token configured but request unauthorized: 401 already sent
};

// When IDM_API_TOKEN is configured, the diagnostics endpoint is gated by the
// same bearer check as mutating endpoints. When the token is empty, the
// endpoint still answers (operational diagnostics) but sensor values and the
// command provenance are redacted so a network observer cannot read live
// climate state or learn whether the mutating API is protected.
DiagnosticsAuth authorize_diagnostics(httpd_req_t *request) {
  const std::string token = CONFIG_IDM_API_TOKEN;
  if (token.empty())
    return DiagnosticsAuth::kRedacted;
  char header[384]{};
  if (httpd_req_get_hdr_value_str(
          request, "Authorization", header, sizeof(header)) != ESP_OK) {
    httpd_resp_set_hdr(request, "WWW-Authenticate", "Bearer");
    send_error(request, "401 Unauthorized", "missing bearer token");
    return DiagnosticsAuth::kBlocked;
  }
  const std::string expected = "Bearer " + token;
  if (!constant_time_equal(header, expected)) {
    httpd_resp_set_hdr(request, "WWW-Authenticate", "Bearer");
    send_error(request, "401 Unauthorized", "invalid bearer token");
    return DiagnosticsAuth::kBlocked;
  }
  return DiagnosticsAuth::kFull;
}

// Replace sensor and command-provenance fields with non-sensitive surrogates.
// Called when the diagnostics request is unauthenticated and IDM_API_TOKEN is
// unset. Operational fields (bridge_state, safe_active/stale/fault, uptime,
// free_heap, output_attempts/failures, network_connected, mutating_api_enabled)
// remain visible for commissioning diagnostics.
void redact_diagnostics(cJSON *root) {
  cJSON_ReplaceItemInObjectCaseSensitive(
      root, "effective_humidity", cJSON_CreateNull());
  cJSON_ReplaceItemInObjectCaseSensitive(
      root, "effective_temperature", cJSON_CreateNull());
  cJSON_ReplaceItemInObjectCaseSensitive(
      root, "dew_point_c", cJSON_CreateNull());
  cJSON_ReplaceItemInObjectCaseSensitive(
      root, "command_source", cJSON_CreateString("redacted"));
  cJSON_ReplaceItemInObjectCaseSensitive(
      root, "humidity_dac_code", cJSON_CreateNull());
  cJSON_ReplaceItemInObjectCaseSensitive(
      root, "temperature_digipot_code", cJSON_CreateNull());
  cJSON_ReplaceItemInObjectCaseSensitive(
      root, "temperature_resistance_ohm", cJSON_CreateNull());
}

bool require_confirmation(
    httpd_req_t *request, const char *expected_value) {
  char header[96]{};
  if (httpd_req_get_hdr_value_str(
          request, "X-IDM-Confirm", header, sizeof(header)) != ESP_OK ||
      std::strcmp(header, expected_value) != 0) {
    send_error(
        request, "409 Conflict",
        "required X-IDM-Confirm header is missing or invalid");
    return false;
  }
  return true;
}

cJSON *read_json_body(httpd_req_t *request) {
  if (request->content_len <= 0 ||
      request->content_len >= static_cast<int>(HTTP_BODY_LIMIT))
    return nullptr;

  char buffer[HTTP_BODY_LIMIT]{};
  int received_total = 0;
  while (received_total < request->content_len) {
    const int received = httpd_req_recv(
        request, buffer + received_total,
        request->content_len - received_total);
    if (received == HTTPD_SOCK_ERR_TIMEOUT)
      continue;
    if (received <= 0)
      return nullptr;
    received_total += received;
  }
  buffer[received_total] = '\0';
  return cJSON_Parse(buffer);
}

bool json_integer_in_range(
    const cJSON *value, int minimum, int maximum, int *result) {
  if (!cJSON_IsNumber(value) || !std::isfinite(value->valuedouble) ||
      std::floor(value->valuedouble) != value->valuedouble ||
      value->valuedouble < minimum || value->valuedouble > maximum)
    return false;
  *result = static_cast<int>(value->valuedouble);
  return true;
}
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
extern "C" void app_main(void) {
  s_runtime_mutex = xSemaphoreCreateMutex();
  if (s_runtime_mutex == nullptr) {
    ESP_LOGE(TAG, "Runtime mutex allocation failed");
    return;
  }

  s_nvs_ready = initialize_nvs();
  const IdmAnalogCalibration factory = factory_calibration();
  if (!valid_calibration(factory)) {
    ESP_LOGE(
        TAG,
        "Configured factory calibration is invalid; using safe defaults");
  }
  const IdmAnalogCalibration safe_factory =
      valid_calibration(factory) ? factory : IdmAnalogCalibration{};
  const IdmAnalogCalibration loaded = load_calibration(safe_factory);

  NativeRuntimeConfig runtime_config{};
  runtime_config.fallback_humidity =
      configured_float(CONFIG_IDM_FALLBACK_HUMIDITY, 80.0f);
  runtime_config.fallback_temperature =
      configured_float(CONFIG_IDM_FALLBACK_TEMPERATURE, 28.0f);
  runtime_config.stale_timeout_ms =
      static_cast<uint32_t>(CONFIG_IDM_STALE_TIMEOUT_SECONDS) * 1000U;
  runtime_config.minimum_command_quality =
      static_cast<uint8_t>(CONFIG_IDM_MINIMUM_COMMAND_QUALITY);
  {
    RuntimeGuard guard;
    s_runtime.configure(runtime_config);
    s_runtime.boot(now_ms(), safe_factory, loaded);
  }

  initialize_watchdog();

  // Hardware outputs are attempted before any network service starts. A
  // missing or failed device latches the runtime into output-fault fallback
  // and is retried without blocking diagnostics or the watchdog.
  const uint32_t startup_ms = now_ms();
  s_boot_ms = startup_ms;
  apply_outputs_once(startup_ms);
  s_next_output_attempt_ms = startup_ms + OUTPUT_RETRY_MS;
  s_next_i2c_attempt_ms = startup_ms + I2C_RETRY_MS;

  // A pending OTA image is no longer confirmed blindly at boot. The health
  // window is evaluated inside the main loop (try_confirm_ota_image), so a
  // crash-looping new image rolls back instead of being accepted.
  initialize_wifi();

  uint32_t next_diagnostic_log_ms = now_ms();
  while (true) {
    const uint32_t current_ms = now_ms();
    {
      RuntimeGuard guard;
      s_runtime.tick(current_ms);
    }

    if (!s_output_hardware.ready &&
        static_cast<int32_t>(current_ms - s_next_i2c_attempt_ms) >= 0) {
      initialize_output_hardware();
      s_next_i2c_attempt_ms = current_ms + I2C_RETRY_MS;
    }
    if (static_cast<int32_t>(
            current_ms - s_next_output_attempt_ms) >= 0) {
      apply_outputs_once(current_ms);
      s_next_output_attempt_ms = current_ms + OUTPUT_RETRY_MS;
    }
    if (static_cast<int32_t>(
            current_ms - next_diagnostic_log_ms) >= 0) {
      log_diagnostics();
      next_diagnostic_log_ms =
          current_ms +
          static_cast<uint32_t>(
              CONFIG_IDM_DIAGNOSTIC_LOG_INTERVAL_SECONDS) *
              1000U;
    }

    try_confirm_ota_image(current_ms);
    esp_task_wdt_reset();
    vTaskDelay(pdMS_TO_TICKS(100));
  }
}

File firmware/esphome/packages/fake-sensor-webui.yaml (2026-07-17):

web_server:
  id: idm_web_server
  port: ${web_port}
  version: 3
  local: true
  include_internal: false
  ota: false
  log: true
  auth:
    username: ${web_username}
    password: ${web_password}
  sorting_groups:
    - id: idm_web_status_group
      name: "1 Status"
      sorting_weight: 10
    - id: idm_web_commands_group
      name: "2 Sollwerte"
      sorting_weight: 20
    - id: idm_web_calibration_group
      name: "3 Kalibrierung"
      sorting_weight: 30
    - id: idm_web_safety_group
      name: "4 Sicherheit"
      sorting_weight: 40
    - id: idm_web_diagnostics_group
      name: "5 Diagnose und Export"
      sorting_weight: 50

esphome:
  on_boot:
    - priority: -100
      then:
        - script.execute: idm_web_sync_calibration_editor
        - text_sensor.template.publish:
            id: idm_web_action_status
            state: "ready"
        # SECURITY: the web server is only safe once web_password is overridden
        # with a real secret. The fail-closed gate is enforced at BUILD time by
        # tools/check_esphome.py, which refuses to validate or compile any
        # device entry point whose web_password substitution still equals the
        # shipped placeholder. An earlier revision tried to add a runtime
        # lambda here calling WebServer::set_enabled(false), but the ESPHome
        # WebServer class (verified against 2026.6.5) exposes no such method,
        # so it failed to compile. The build-time gate is the authoritative
        # safeguard; do not weaken it by re-adding a runtime workaround unless
        # a supported ESPHome API for fully disabling the listener exists.

script:
  - id: idm_web_sync_calibration_editor
    mode: restart
    then:
      - lambda: |-
          const auto &calibration = id(idm_analog_outputs)->calibration();
          id(idm_web_humidity_code_min)->publish_state(
              calibration.humidity_code_min);
          id(idm_web_humidity_code_max)->publish_state(
              calibration.humidity_code_max);
          id(idm_web_temperature_resistance_min)->publish_state(
              calibration.temperature_resistance_min);
          id(idm_web_temperature_resistance_max)->publish_state(
              calibration.temperature_resistance_max);
          id(idm_web_temperature_code_inverted)->publish_state(
              calibration.temperature_code_inverted);

  - id: idm_web_expire_confirmation
    mode: restart
    then:
      - delay: 60s
      - switch.template.publish:
          id: idm_web_dangerous_action_confirmation
          state: OFF
      - text_sensor.template.publish:
          id: idm_web_action_status
          state: "confirmation_expired"

number:
  - platform: template
    id: idm_web_humidity_code_min
    name: "IDM Web Humidity Code Minimum"
    icon: mdi:tune-vertical
    entity_category: config
    optimistic: true
    restore_value: false
    initial_value: 0
    min_value: 0
    max_value: 4095
    step: 1
    mode: box
    web_server:
      sorting_group_id: idm_web_calibration_group
      sorting_weight: 10

  - platform: template
    id: idm_web_humidity_code_max
    name: "IDM Web Humidity Code Maximum"
    icon: mdi:tune-vertical
    entity_category: config
    optimistic: true
    restore_value: false
    initial_value: 4095
    min_value: 0
    max_value: 4095
    step: 1
    mode: box
    web_server:
      sorting_group_id: idm_web_calibration_group
      sorting_weight: 20

  - platform: template
    id: idm_web_temperature_resistance_min
    name: "IDM Web Temperature Resistance Minimum"
    icon: mdi:resistor
    entity_category: config
    optimistic: true
    restore_value: false
    initial_value: 650
    min_value: 100
    max_value: 50000
    step: 10
    unit_of_measurement: "Ω"
    mode: box
    web_server:
      sorting_group_id: idm_web_calibration_group
      sorting_weight: 30

  - platform: template
    id: idm_web_temperature_resistance_max
    name: "IDM Web Temperature Resistance Maximum"
    icon: mdi:resistor
    entity_category: config
    optimistic: true
    restore_value: false
    initial_value: 3000
    min_value: 100
    max_value: 50000
    step: 10
    unit_of_measurement: "Ω"
    mode: box
    web_server:
      sorting_group_id: idm_web_calibration_group
      sorting_weight: 40
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

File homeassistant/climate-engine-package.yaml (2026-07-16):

# WIP example. Replace entity IDs and test in a non-safety-critical environment.
#
# Compatibility:
# - The raw write_register actions work with the latest released
#   idm-heatpump-hass v0.8.2.
# - Upstream main also contains set_external_climate. After that service is
#   released, the two raw writes below can be replaced by one native call.

input_number:
  idm_sensor_stale_after_minutes:
    name: IDM sensor stale after
    icon: mdi:timer-alert-outline
    unit_of_measurement: min
    min: 1
    max: 120
    step: 1
    initial: 15
  idm_fallback_temperature:
    name: IDM fallback temperature
    icon: mdi:thermometer-alert
    unit_of_measurement: "°C"
    min: 15
    max: 30
    step: 0.5
    initial: 28
  idm_fallback_humidity:
    name: IDM fallback humidity
    icon: mdi:water-alert
    unit_of_measurement: "%"
    min: 1
    max: 100
    step: 1
    initial: 80

input_text:
  idm_external_climate_publish_status:
    name: IDM external climate publish status
    icon: mdi:cloud-upload-outline
    max: 100
    initial: not_attempted_since_restart

input_datetime:
  idm_last_external_climate_publish:
    name: IDM last successful external climate publish
    icon: mdi:clock-check-outline
    has_date: true
    has_time: true

template:
  - triggers:
      - trigger: state
        entity_id:
          - sensor.living_temperature
          - sensor.living_humidity
          - sensor.bedroom_temperature
          - sensor.bedroom_humidity
          - sensor.office_temperature
          - sensor.office_humidity
          - sensor.cooling_flow_temperature
          - input_number.idm_sensor_stale_after_minutes
          - input_number.idm_fallback_temperature
          - input_number.idm_fallback_humidity
          - input_text.idm_external_climate_publish_status
          - input_datetime.idm_last_external_climate_publish
      - trigger: time_pattern
        minutes: "/1"
      - trigger: homeassistant
        event: start
    actions:
      - variables:
          idm_selected_room: >
            {% set stale_after = states('input_number.idm_sensor_stale_after_minutes') | float(15) * 60 %}
            {% set fallback_temperature = states('input_number.idm_fallback_temperature') | float(28) %}
            {% set fallback_humidity = states('input_number.idm_fallback_humidity') | float(80) %}
            {% set rooms = [
              {'name': 'living', 'temperature': 'sensor.living_temperature', 'humidity': 'sensor.living_humidity'},
              {'name': 'bedroom', 'temperature': 'sensor.bedroom_temperature', 'humidity': 'sensor.bedroom_humidity'},
              {'name': 'office', 'temperature': 'sensor.office_temperature', 'humidity': 'sensor.office_humidity'}
            ] %}
            {% set ns = namespace(
              name='fallback',
              temperature=fallback_temperature,
              humidity=fallback_humidity,
              dew_point=-99,
              any_stale=false,
              uses_fallback=true,
              source_age_seconds=999999,
              reason='fallback_no_valid_room'
            ) %}
            {% set now_timestamp = as_timestamp(now()) %}
            {% for room in rooms %}
              {% set temperature_state = expand(room.temperature) | first | default(none) %}
              {% set humidity_state = expand(room.humidity) | first | default(none) %}
              {% set fresh = false %}
              {% set maximum_age = 999999 %}
              {% if temperature_state is not none and humidity_state is not none
                    and is_number(temperature_state.state)
                    and is_number(humidity_state.state) %}
                {% set raw_temperature = temperature_state.state | float %}
                {% set raw_humidity = humidity_state.state | float %}
                {% set valid_range = -40 <= raw_temperature <= 80
                                     and 0 < raw_humidity <= 100 %}
                {% set maximum_age = [
                  now_timestamp - as_timestamp(temperature_state.last_reported, 0),
                  now_timestamp - as_timestamp(humidity_state.last_reported, 0)
                ] | max %}
                {% set fresh = valid_range
                               and 0 <= maximum_age <= stale_after %}
              {% endif %}
              {% if fresh %}
                {% set temperature = temperature_state.state | float %}
                {% set humidity = humidity_state.state | float %}
              {% else %}
                {% set temperature = fallback_temperature %}
                {% set humidity = fallback_humidity %}
                {% set ns.any_stale = true %}
              {% endif %}
              {% set humidity = clamp(humidity, 1, 100) %}
              {% set gamma = ((17.62 * temperature) / (243.12 + temperature)) + log(humidity / 100) %}
              {% set dew_point = (243.12 * gamma) / (17.62 - gamma) %}
              {% if dew_point > ns.dew_point %}
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

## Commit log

2026-07-15 Initialize IDM room sensor repository
2026-07-16 initial release v 0.2.0
    [BOM-template.csv, BOM.csv, IDM-FakeSensor-ESP.kicad_pcb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]
2026-07-16 Complete software and firmware backlog
    [partitions.csv]
2026-07-17 Härtung und Aufräumarbeiten: P1–P4 Implementierung (#7)
    * P1: safety and security hardening (fail-closed)
    - MQTT: add username/password wiring + fix discover_ip typo; device entry
    points ship sentinel placeholders; tools/check_esphome.py refuses to
    validate while placeholders remain (fail-closed gate).
    - Web UI: runtime-disable defense in depth when web_password is still the
    shipped placeholder.
    - Native diagnostics: bearer-gate when IDM_API_TOKEN is set, otherwise
    redact sensor/command-provenance fields (operational fields stay visible).
    - OTA: health-gated image confirmation (no longer blindly valid on every
    boot) + optional IDM_OTA_ALLOWED_HOST allowlist + IDM_OTA_HEALTH_SE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
    [fake-sensor-bridge.yaml]
2026-07-17 fix(ci): let ESPHome compile proof run with synthetic CI credentials (#9)
    The P1 fail-closed gate rejects device entry points that still carry the
    shipped credential placeholders. That is correct for production, but it also
    blocked the CI compile job from proving the device configs still build
    (compile job failed in #7: 'esp-sensor-esphome.yaml still carries placeholder
    credential(s): idm-mqtt-CHANGE-ME').
    check_esphome.py now supports --ci (only with --compile): it writes a
    throwaway copy of each device entry point next to the original — so relative
    !include paths still resolve — substitutes non-secret synthetic credentials,
    compiles that copy, and removes it. The committed files keep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
2026-07-17 fix(ci): apply --ci credential override during validate too (#10)
    The previous fix (#9) only substituted synthetic credentials during compile,
    but check_esphome.py runs validate (esphome config) first, which still hit
    the fail-closed placeholder gate on the committed device entry points and
    failed the CI compile job before compilation even started.
    validate() now takes the same ci flag: in CI mode it validates a throwaway
    override copy of each device entry point instead of the committed placeholder
    file. The committed files still ship their fail-closed placeholders; nothing
    real reaches a device. Also refactored the esphome subprocess call into a
    shared helper and dropped the now-pointless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
2026-07-17 fix(esphome): use discover_ip, the option ESPHome 2026.6.5 actually knows (#11)
    The ESPHome compile CI job failed:
    [discovery_ip] is an invalid option for [mqtt]. Did you mean
    [discover_ip], [discovery], [discovery_retain]?
    P1 'corrected' discover_ip to discovery_ip based on ambiguous docs, but the
    installed ESPHome release only accepts discover_ip. Revert to the canonical
    spelling the schema validator recognizes, and pin a comment + contract test
    so the mistake cannot silently return.
2026-07-17 fix(esphome): remove invalid WebServer::set_enabled runtime lambda (#12)
    fake-sensor-webui.yaml:45:25: error: 'class esphome::web_server::WebServer'
    has no member named 'set_enabled'
    P1.2 added a runtime 'defense in depth' lambda that called
    id(idm_web_server).set_enabled(false) when web_password was still the shipped
    placeholder. The ESPHome WebServer class (verified against 2026.6.5) exposes
    no such method, so the device config did not compile. The authoritative
    fail-closed safeguard is the build-time gate in tools/check_esphome.py (which
    rejects placeholder credentials before validation/compile); the runtime lambda
    was only secondary and is not expr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
    [fake-sensor-webui.yaml]
